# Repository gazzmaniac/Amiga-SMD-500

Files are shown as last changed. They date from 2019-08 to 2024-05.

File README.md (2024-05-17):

SMD 500+
Licensed under the CERN Open Hardware Licence Version 2 - Strongly Reciprocal.  https://cern-ohl.web.cern.ch/.

Warning and Disclaimer - May 2024
-------------------------------------------------------
Be advised that this project was only developed to a working prototype.  It has not been updated since 2019.
There are significant issues with it, not least of which are many of the holes and plugs do not line up with the A500 case.
If you want to build a replacement A500 or A500+ you should build a different project.
These files are made available in case somebody ever wants to use them as the basis for another project.
No support will be given by the author should you choose to ignore this advice and build it anyway.
Note the change in license.  Feel free to use this project but I do ask that any derivative projects give credit and are also open source.
No other changes have been made to this project.

Introduction
-------------------------------------------------------
The SMD 500+ project is a re-creation of the great Commodore Amiga 500/500+ using modern surface mounted components except for the CPU, custom chips, and CIAs.

The schematics are based on the schematics provided by Commodore in the Amiga 500+ user manual.
Each of the SMD components (except for the chip ram) was verified as available from Mouser in June 2019.  Anyone looking to construct the board would need a donor A500/A500+ or A2000 board in order to obtain the custom chips.

Features
-------------------------------------------------------
Certain experimental features have been added, most notably the ability to use either the 1 mb 8372 Agnus or the 2 mb 8375 Agnus, which are not pin-compatible with each other.  The board is set up to use the 8375 by default but can be changed simply by changing a couple of jumpers.

SVideo and Composite is supplied by an AD723 PAL encoder.  PAL only at this stage (sorry America).

The rechargeable battery has been substituted for a coin cell and diode (Aminet hack) and the RTC area has been slightly modified to allow for the RTC72421 IC to be used.

An option for a single HYB5118160BSJ 1Mx16 2 mb chip ram IC is available instead of using the eight 256kx4 TTH ICs.  The board is set up for the HYB5118160BSJ by default but can easily be changed with jumpers.  Note this modification is probably the most experimental of the lot and I am not 100% confident that there is not a mistake.

The power input socket is the same as Chucky Hertell's Re-Amiga 1200 board - i.e. you can use either the normal square DIN or a round DIN.

The EMF filters have been replaced with resistors and capacitors same as on the Amiga 1200.

Version 0.11 and 0.12 notes
-------------------------------------------------------
Minor revisions to fix a problem with the solder mask layer

Version 0.1 notes (also in the schematic)
-------------------------------------------------------

ADDED OPTION FOR ONE HYB5118160BSJ 1Mx16BIT CHIP RAM IC
REMOVED A501+ (PP12&13) FROM THESE SCHEMATICS 
(CONNECTOR P9 IS STILL THERE)

CHANGED BT9 TO COIN CELL AND DIODE
MINOR MODIFICATION TO ALLOW RTC72421

ADDED OPTION FOR AGNUS 8572.  CHANGE JP2 FOR 8572 
AND INSTALL FB101.1

ADD OPTION FOR ROUND DIN POWER INPUT

RESISTOR PACKS CHANGED FOR INDIVIDUAL RESISTORS

RTC REMOVED FROM A501 SCHEMATIC

REPLACED EMF FILTERS ON JOY1, JOY2, PARALLEL, SERIAL,
EXTERNAL FLOPPY, VIDEO OUT, CLOCKS, AUDIO, KB
WITH Rs, Cs, & FBs, A LA A1200

SVIDEO AND COLOUR COMPOSITE OUTPUT USING  AD723

U33.1 AND C33.1 REQUIRED IF USING AD723 OR 8372.

ONLY POPULATE EITHER U201 (2 MB SMD HYB5118160BSJ 1Mx16)
OR U16-23 (256Kx4 TTH FROM A500+).  

POPULATE C297-C299 FOR U201
POPULATE C16-C23 AND R209 FOR U16-U23

DO NOT INSTALL TRAP DOOR RAM WHEN U24 IS POPULATED

IF USING 1 MB AGNUS DO NOT INSTALL TRAP DOOR 
WHEN U20-23 ARE POPULATED

JUMPERS SET TO USE U201 AS DEFAULT
JP4 SET TO BYPASS U32 AS U201 HAS AN A9 LINE
JP98 CONNECTS THE TWO _RAS LINES

IF USING TTH 256Kx4 ICS (SAME AS ORIGINAL A500+ MACHINE)
POPULATE U32 AND BREAK JP4 AND JP98
JP3 SWAPS UPPER AND LOWER RAM BANKS FOR 256Kx4 CHIPS

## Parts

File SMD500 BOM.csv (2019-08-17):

Id | Designator | Package | Quantity | Designation | Supplier and ref
1 | U5 | DIP-48_W15.24mm_LongPads | 1 | 5719_Gary
2 | U7,U8 | DIP-40_W15.24mm_LongPads | 2 | 8520_CIA
3 | U39 | SOIC127P600X175-14N | 1 | MAX1489ECSD+
4 | R456,R458,R454 | R_0805_2012Metric_Pad1.15x1.40mm_HandSolder | 3 | 374R
5 | HY1 | PinHeader_1x22_P2.54mm_Vertical | 1 | VIDEOHYBRID
6 | U41,U40 | SOIC127P1030X265-20N | 2 | SN74HCT245DWR
7 | U2.2 | PLCC-84_THT-Socket | 1 | 8372_FatAgnus1MB
8 | BT9 | SMTU2032LF | 1 | COINCELL
9 | U2.1 | PLCC-84_THT-Socket | 1 | 8375_FatAgnus2MB
10 | U201 | SOJ-42 | 1 | HYB5118160BSJ
11 | U20,U23,U22,U21,U19,U18,U17,U16 | DIP-20_W7.62mm_LongPads | 8 | HYB514256B
12 | U11,U34,U13 | SOIC127P1030X265-20N | 3 | SN74LS373DW
13 | U10,U12 | SOIC127P1030X265-20N | 2 | SN74LS244DW
14 | U1 | DIP-64_W22.86mm_LongPads | 1 | 68000D
15 | G***,G***,G*** | RedKeg500 | 3 | LOGO
16 | TC9 | C_Trimmer_Voltronics_JZ | 1 | 8-40 pF (JZ400)
17 | C402,C401,C307 | CAPAE1350X1400N | 3 | 1000 uF
18 | D912,D99 | SOD3716X115N | 2 | 1N4148W-7-F
19 | Y460 | XTAL_HC49 | 1 | 17.734 475 MHz 18 pF
20 | Y9 | LFXTAL002995BULK | 1 | LFXTAL002995Bulk
21 | X1 | Oscillator_DIP-14 | 1 | ACO-28.37516MHz
22 | V20,V19,V18,V17,V16,V15,V14,V13,V12,V11,V10,V9,V8,V7,V6,V5,V4,V3,V2,V1 | SolderWirePad_1x01_Drill0.8mm | 20 | Conn_01x01_Male
23 | U45 | AD723ARUZ | 1 | AD723ARUZ
24 | U42 | SOIC127P600X175-8N | 1 | NE555DR
25 | U38 | SOIC127P600X175-14N | 1 | MAX1488ECSD+
26 | U37 | SN74LS32NSR | 1 | 74LS32
27 | U36 | SOIC127P600X175-14N | 1 | SN74LS05DR
28 | U35 | SOIC127P1032X265-20N | 1 | N74F244D
29 | U33.1 | SN74F04DR | 1 | SN74F04DR
30 | U33 | SOIC127P600X175-16N | 1 | SN74F258D
31 | U32 | MC74AC139DR2G | 1 | MC74AC139DR2G
32 | U15 | SN74LS157DR | 1 | SN74LS157DR
33 | U14 | SOIC127P600X175-14N | 1 | TL084
34 | U9 | DIP-18_W7.62mm_LongPads | 1 | RTC72421
35 | U6 | DIP-42_W15.24mm_Socket_LongPads | 1 | ROM_SOCKET
36 | U4 | DIP-48_W15.24mm_LongPads | 1 | 8373_DeniseECS
37 | U3 | DIP-48_W15.24mm_LongPads | 1 | 8364_Paula
38 | TP9 | TestPoint_Pad_1.0x1.0mm | 1 | TestPoint
39 | RP501.5,RP501.6,RP501.4,RP501.3,RP501.2,RP501.7,RP501.8,RP501.1,R914,R912,R506,R505,R501,R339,R333,R332,R323,R322,R308,R306 | R_0805_2012Metric_Pad1.15x1.40mm_HandSolder | 20 | 10K
40 | RP403.2,RP403.5,RP402.1,RP402.2,RP402.3,RP402.4,RP402.5,RE531,RE434 | R_0805_2012Metric_Pad1.15x1.40mm_HandSolder | 9 | 47R
41 | RP403.3,RP403.4,RP403.1,RP203.2,RP203.1,RP203.3,RP203.4,RP203.5,RP202.2,RP202.4,RP202.1,RP202.3,RP202.5,RP201.1,RP201.3,RP201.2,RP201.5,RP201.4,RE626,RE619,RE618,RE616,RE612,RE611,RE538,RE537,RE536,RE535,RE534,RE533,RE532,RE524,RE523,RE522,RE521,RE520,RE519,RE518,RE517,RE516,RE515,RE514,RE513,RE512,RE511,RE499,RE427,RE426,RE425,RE424,RE423,RE422,RE421,RE417,RE416,RE415,RE414,RE413,RE412,RE411,R109 | R_0805_2012Metric_Pad1.15x1.40mm_HandSolder | 61 | 68R
42 | RP401.4,RP401.6,RP401.3,RP401.2,RP401.1,RP401.7,RP401.8,RP401.5,RP111.6,RP111.5,RP111.4,RP111.9,RP111.8,RP111.3,RP111.2,RP111.7,RP111.1,RP110.8,RP110.2,RP110.3,RP110.4,RP110.5,RP110.6,RP110.7,RP110.9,RP110.1,RP109.1,RP109.7,RP109.6,RP109.5,RP109.4,RP109.3,RP109.2,RP109.8,RP109.9,RP108.2,RP108.8,RP108.3,RP108.4,RP108.5,RP108.6,RP108.7,RP108.1,RP108.9,RP107.9,RP107.1,RP107.7,RP107.8,RP107.2,RP107.4,RP107.5,RP107.3,RP107.6,RP106.7,RP106.6,RP106.5,RP106.1,RP106.4,RP106.8,RP106.3,RP106.2,RP106.9,RP105.9,RP105.7,RP105.2,RP105.3,RP105.4,RP105.6,RP105.5,RP105.1,RP102.4,RP102.7,RP102.3,RP102.6,RP102.1,RP102.5,RP102.2,RP101.8,RP101.2,RP101.1,RP101.3,RP101.4,RP101.5,RP101.6,RP101.7,R504,R503,R404,R403,R402,R209,R202,R201 | R_0805_2012Metric_Pad1.15x1.40mm_HandSolder | 93 | 4.7K
43 | RP104.2,RP104.1,RP104.4,RP104.5,RP104.7,RP104.8,RP104.9,RP104.3,RP104.6 | R_0805_2012Metric_Pad1.15x1.40mm_HandSolder | 9 | 470R
44 | RP103.3,RP103.2,RP103.4,RP103.1 | R_0805_2012Metric_Pad1.15x1.40mm_HandSolder | 4 | 39R
45 | RE625,RE624,RE623,RE622,RE621,RE620,RE617,RE615,RE614,RE613,RE105,RE104 | R_0805_2012Metric_Pad1.15x1.40mm_HandSolder | 12 | 27R
46 | RE444,RE443,RE442,RE441,RE303,RE302 | R_0805_2012Metric_Pad1.15x1.40mm_HandSolder | 6 | 0R
47 | R916,R915,R713,R334,R324,R305,R304,R303,R192,R191 | R_0805_2012Metric_Pad1.15x1.40mm_HandSolder | 10 | 1K
48 | R712 | R_0805_2012Metric_Pad1.15x1.40mm_HandSolder | 1 | 47K
49 | R711,R461 | R_0805_2012Metric_Pad1.15x1.40mm_HandSolder | 2 | 1M
50 | R507 | R_0805_2012Metric_Pad1.15x1.40mm_HandSolder | 1 | 100R
51 | R502,R307 | R_0805_2012Metric_Pad1.15x1.40mm_HandSolder | 2 | 2.7K
52 | R460 | R_0805_2012Metric_Pad1.15x1.40mm_HandSolder | 1 | 200R
53 | R457,R455,R453 | R_0805_2012Metric_Pad1.15x1.40mm_HandSolder | 3 | 300R
54 | R452,R451,R450 | R_0805_2012Metric_Pad1.15x1.40mm_HandSolder | 3 | 75R
55 | R409 | R_0805_2012Metric_Pad1.15x1.40mm_HandSolder | 1 | 150R
56 | R408,R406,R401 | R_0805_2012Metric_Pad1.15x1.40mm_HandSolder | 3 | 4.7R 0.5W
57 | R405 | R_0805_2012Metric_Pad1.15x1.40mm_HandSolder | 1 | 0.47R 0.5W
58 | R336,R326 | R_0805_2012Metric_Pad1.15x1.40mm_HandSolder | 2 | 470K
59 | R335,R325 | R_0805_2012Metric_Pad1.15x1.40mm_HandSolder | 2 | 390R
60 | R331,R321 | R_0805_2012Metric_Pad1.15x1.40mm_HandSolder | 2 | 360R
61 | R309 | R_0805_2012Metric_Pad1.15x1.40mm_HandSolder | 1 | 1R 0.5W
62 | R302,R301 | R_0805_2012Metric_Pad1.15x1.40mm_HandSolder | 2 | 10R
63 | R114,R112,R111 | R_0805_2012Metric_Pad1.15x1.40mm_HandSolder | 3 | 68
64 | R113,R107,R106,R105,R104,R103 | R_0805_2012Metric_Pad1.15x1.40mm_HandSolder | 6 | 47
65 | R102,R101 | R_0805_2012Metric_Pad1.15x1.40mm_HandSolder | 2 | 27
66 | Q711,Q501 | SOT-23-3 | 2 | MMBT3904-TP
67 | Q503,Q502,Q301 | SOT-23-3 | 3 | MMBT3906-TP
68 | Q331,Q321 | PMBF4391 | 2 | PMBF4391
69 | P9 | PinHeader_2x28_P2.54mm_Vertical(Mirror) | 1 | Conn_02x28_Odd_Even
70 | P1 | 86 pin edge connector | 1 | EDGE86
71 | MT7,MT6,MT5,MT4,MT2,MT1 | MountingHole_4mm_Pad_Via | 6 | MountingHole_Pad
72 | LF1 | Amiga Line Filter | 1 | AmigaLineFilter
73 | L450 | L_0805_2012Metric_Pad1.15x1.40mm_HandSolder | 1 | 68uH
74 | JP450,JP199,JP98,JP10.2,JP10.1,JP1 | SolderJumper-2_P1.3mm_Bridged_Pad1.0x1.5mm | 6 | SolderJumper_2_Bridged
75 | JP99.1,JP99.2,JP8,JP7.2,JP7.1,JP4.2,JP4.1 | SolderJumper-3_P1.3mm_Bridged12_Pad1.0x1.5mm_NumberLabels | 7 | SolderJumper_3_Bridged12
76 | JP11 | SolderJumper-3_P1.3mm_Bridged12_Pad1.0x1.5mm_NumberLabels | 1 | SolderJumper_3_Bridged1-2
77 | JP9 | SolderJumper-2_P1.3mm_Open_Pad1.0x1.5mm | 1 | SolderJumper_2_Open
78 | JP3.1,JP3.2 | SolderJumper-2_P1.3mm_Bridged_Pad1.0x1.5mm | 2 | Jumper_2_Bridged
79 | JP2 | SolderJumper-3_P1.3mm_Bridged12_Pad1.0x1.5mm_NumberLabels | 1 | SolderJumper_3_Bridged12_2
80 | FB802,E435 | R_0805_2012Metric_Pad1.15x1.40mm_HandSolder | 2 | FB
81 | FB704,FB703,FB702,FB602,FB601,E498,E433,E432,E431,E407,E406.1,E406.2,E405,E404,E403,E402,E110,E101 | R_0805_2012Metric_Pad1.15x1.40mm_HandSolder | 18 | FB200R
82 | FB102 | R_0805_2012Metric_Pad1.15x1.40mm_HandSolder | 1 | 150R@100MHz
83 | FB101 | R_0805_2012Metric_Pad1.15x1.40mm_HandSolder | 1 | 68R@100MHz
84 | E794,E793,E792,E791 | C_0805_2012Metric | 4 | 47 pF
85 | E666 | C_0805_2012Metric | 1 | 22 pF
86 | E632,E631 | C_0805_2012Metric | 2 | 100 pF
87 | E503,E502,E501 | R_0805_2012Metric_Pad1.15x1.40mm_HandSolder | 3 | 47R 0.5W
88 | E306,E305 | C_0805_2012Metric_Pad1.15x1.40mm_HandSolder | 2 | 270 pF
89 | E109,E108,E107,E106,E103,E102,C403 | C_0805_2012Metric_Pad1.15x1.40mm_HandSolder | 7 | 47 pF
90 | D501 | D_DO-35_SOD27_P7.62mm_Horizontal | 1 | 1N914
91 | CN45,CN15 | HDRV4W69P0X250_1X4_1000X500X1040P | 2 | Conn_01x04
92 | CN14,CN12 | TE_2-171825-4 | 2 | 2-171825-4
93 | CN13 | PinHeader_1x08_P2.54mm_Vertical | 1 | 1x8HEADER
94 | CN11 | PinHeader_2x17_P2.54mm_Vertical | 1 | 2x17
95 | CN10 | PJRAN1X1U03AUX | 1 | PJRAN1X1U03AUX(YELLOW)
96 | CN9 | DSUB-23_Male_Horizontal_P2.77x2.84mm_EdgePinOffset4.94mm_Housed_MountingHolesOffset7.48mm | 1 | DB23
97 | CN8 | A500 Power | 1 | SQ&RNDDIN
98 | CN7 | D25S33E4PA00LF | 1 | DB25S
99 | CN6 | D25P13B4PA00LF | 1 | DB25P
100 | CN5 | DSUB-23_Female_Horizontal_P2.77x2.84mm_EdgePinOffset4.94mm_Housed_MountingHolesOffset7.48mm | 1 | DB23_Female_MountingHoles
101 | CN4 | PJRAN1X1U03AUX | 1 | PJRAN1X1U02AUX(WHITE)
102 | CN3 | PJRAN1X1U03AUX | 1 | PJRAN1X1U03AUX(RED)
103 | CN2,CN1 | D09P13B4PA00LF | 2 | DB9-M
104 | CE704,CE703,CE702,CE602,CE601,CE531,CE501,CE498,CE407,CE405,CE404,CE403,CE402,CE110,CE101,C803,C802,C801,C800,C713,C701,C308,C39,C37,C36,C35,C34,C33,C33.1,C32,C15,C12,C10,C8,C7 | C_0805_2012Metric_Pad1.15x1.40mm_HandSolder | 35 | 0.01 uF
105 | CE626,CE625,CE624,CE623,CE622,CE621,CE620,CE619,CE618,CE617,CE616,CE615,CE614,CE613,CE612,CE611,CE538,CE537,CE536,CE535,CE534,CE533,CE532,CE525,CE524,CE523,CE522,CE521,CE519,CE518,CE517,CE516,CE515,CE514,CE513,CE512,CE511,CE499,CE434,CE433,CE432,CE431,CE403.4,CE403.3,CE403.1,CE402.4,CE402.3,CE402.2,CE402.5 | C_0805_2012Metric_Pad1.15x1.40mm_HandSolder | 49 | 100 pF
106 | CE444,CE443,CE442,CE441,C423,C422,C421,C413,C412,C411 | C_0805_2012Metric_Pad1.15x1.40mm_HandSolder | 10 | 470 pF
107 | CE424,CE423,CE422,CE421,CE414,CE413,CE412,CE411,CE303,CE302,C332,C322 | C_0805_2012Metric_Pad1.15x1.40mm_HandSolder | 12 | 6800 pF
108 | CE408,CE401 | C_0805_2012Metric_Pad1.15x1.40mm_HandSolder | 2 | 0.22 uF
109 | CE105,CE104 | C_0805_2012Metric_Pad1.15x1.40mm_HandSolder | 2 | 68 pF
110 | C913 | EEEHB1E4R7AR | 1 | 4.7 uF
111 | C911 | C_0805_2012Metric_Pad1.15x1.40mm_HandSolder | 1 | 22 pF
112 | C822,C821 | CP_Elec_6.3x7.7 | 2 | 47 uF
113 | C816,C815,C814,C813,C812,C811 | CP_Elec_6.3x7.7 | 6 | 100 uF
114 | C804,C502,C501,C335,C325,C305,C302,C301,C42,C41,C40,C23,C22,C21,C20,C19,C18,C17,C16,C14,C13,C11,C9,C6,C5,C4,C3,C2,C1 | C_0805_2012Metric_Pad1.15x1.40mm_HandSolder | 29 | 0.33 uF
115 | C712,C306,C45.1 | CP_Elec_4x5.7 | 3 | 10 uF
116 | C711,C451,C450,C331,C321,C45.3,C45.2 | C_0805_2012Metric_Pad1.15x1.40mm_HandSolder | 7 | 0.1 uF
117 | C461 | C_0805_2012Metric_Pad1.15x1.40mm_HandSolder | 1 | 39 pF
118 | C460 | C_0805_2012Metric_Pad1.15x1.40mm_HandSolder | 1 | 33 pF
119 | C453 | C_0805_2012Metric_Pad1.15x1.40mm_HandSolder | 1 | 18 pF
120 | C452 | C_0805_2012Metric_Pad1.15x1.40mm_HandSolder | 1 | 0.1u
121 | C334,C324,C304,C303 | CP_Elec_6.3x5.3 | 4 | 22 uF
122 | C333,C323 | C_0805_2012Metric_Pad1.15x1.40mm_HandSolder | 2 | 3900 pF
123 | C314,C313,C312,C311 | C_0805_2012Metric_Pad1.15x1.40mm_HandSolder | 4 | 0.047 uF
124 | C299,C298 | C_0805_2012Metric_Pad1.15x1.40mm_HandSolder | 2 | 0.47 uF

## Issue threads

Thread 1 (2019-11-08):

Is there a forum or other discussion area?

abrugsch, 2019-11-08:
I found someone selling a copy of this this board on ebay and it's something that I wanted to do myself (glad to see you're using KiCad... I can contribute pull requests ;) ). The A500++ is all well and good but it uses the exact same through hole parts as the original. I'd like to see how people building this are getting on as I love that it has a load of the modern mods built right in.

Is there a dev thread on EAB? or a discord server such as Official Commodore Amiga, Retro Man Cave, Amiga Bill's?

gazzmaniac, 2019-11-09:
I haven't got any formal discussion etc. but I am making one and posting progress on Facebook at facebook.com/redkegtech.
I have no idea if anyone has got one running yet.  I've got an issue getting sync from Agnus but I'm away for work for a couple of weeks so progress has stalled.

Closed 2019-11-09.

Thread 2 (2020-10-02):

is this board tested?

arjanv, 2020-10-02:
is this board tested?

thanks

gazzmaniac, 2020-10-02:
It works but no guarantees.As per the readme.

  On Fri., 2 Oct. 2020 at 10:43 pm, arjanv<notifications@github.com> wrote:

is this board tested?

thanks

—
You are receiving this because you are subscribed to this thread.
Reply to this email directly, view it on GitHub, or unsubscribe.

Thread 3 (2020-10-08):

JP98 RAS joined won't work

LIV2, 2020-10-08:
Hi, first of all great work! Love the project

Just thought I'd let you know that recently I was making a Megachip clone for the A500 and found that joining the RAS lines just resulted in a green screen. I had to make use of an OR gate to get this working - an 74AHC1G08 in my case.

Presumably this is because the RAS lines are not open-collector and fight each other when you simply join them together

mariuszk911, 2020-10-08:
Or just use two diodes... Like on 2M Mod for 8A1 using SOJ memory modules.

gazzmaniac, 2022-04-20:
I never did get the single ram IC solution working.  I'm looking at doing a revision later in the year and will have chip ram on two chips.

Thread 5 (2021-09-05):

gerber errors

kipper2k, 2021-09-05:
Hi all, i am looking at the gerbers i uploaded to...  https://gerber-viewer.easyeda.com/showcase/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

I found some traces that seem to be incorrect, here is a picture, there may be more.

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

gazzmaniac, 2022-04-20:
Hi Kipper!
Thanks for letting me know.  I am looking at doing a revision this year, and intend to replace the TTH ram with two SMD chips like the A1200 has.

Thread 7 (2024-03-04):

A question about fitting the board

leventpekcan, 2024-03-04:
Hello,

I received a fully built, working SMD500+ from my friend and trying to build myself a modern A500+ with it. The problem is, the board does not fit into the original metal shielding of A500+. Even without the shielding, some of the screw holes does not align with the bottom plastic part (Original A500+). What could be the problem?

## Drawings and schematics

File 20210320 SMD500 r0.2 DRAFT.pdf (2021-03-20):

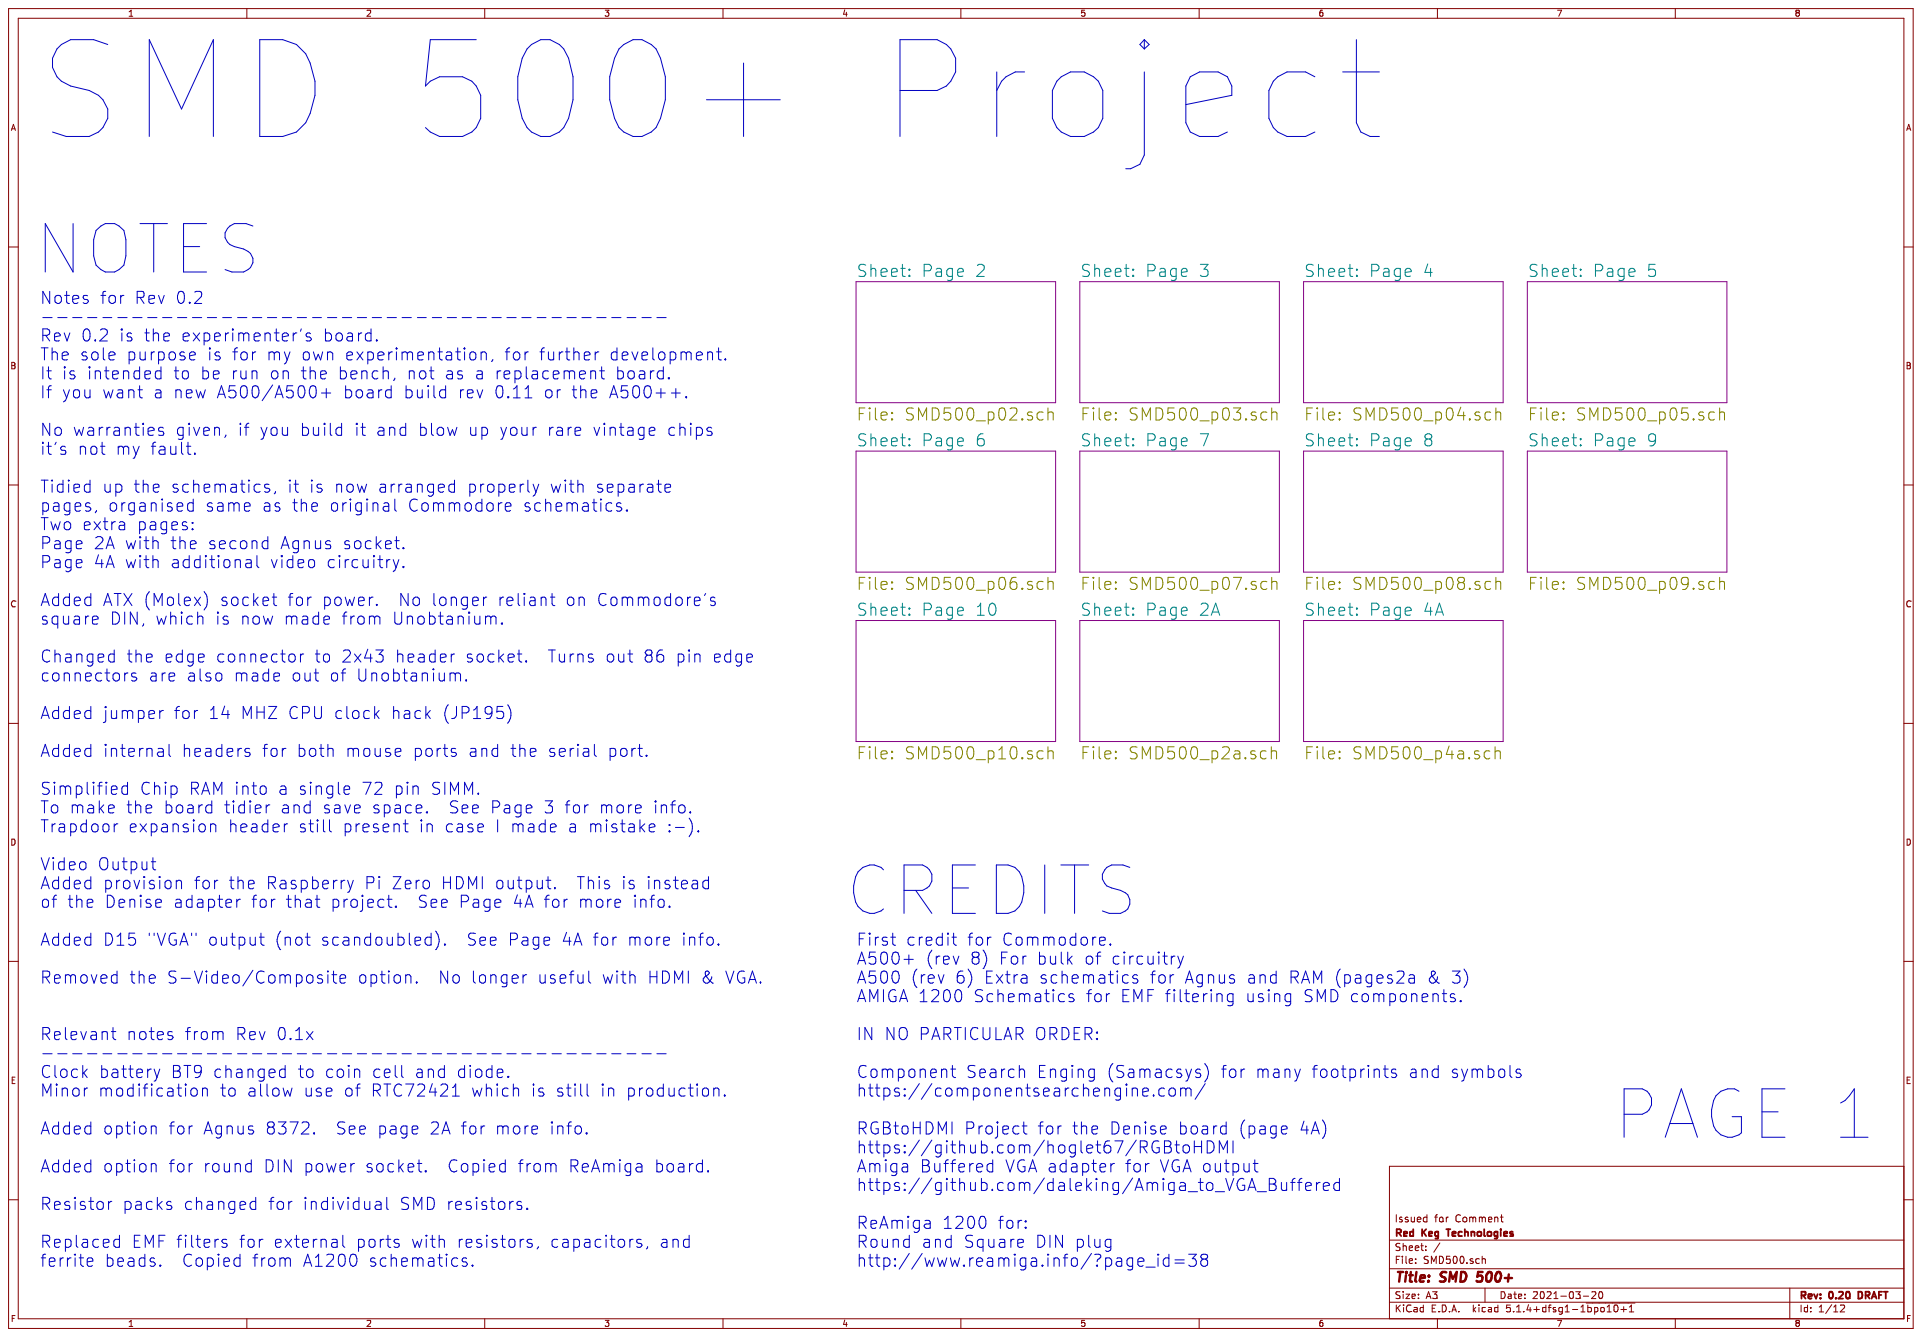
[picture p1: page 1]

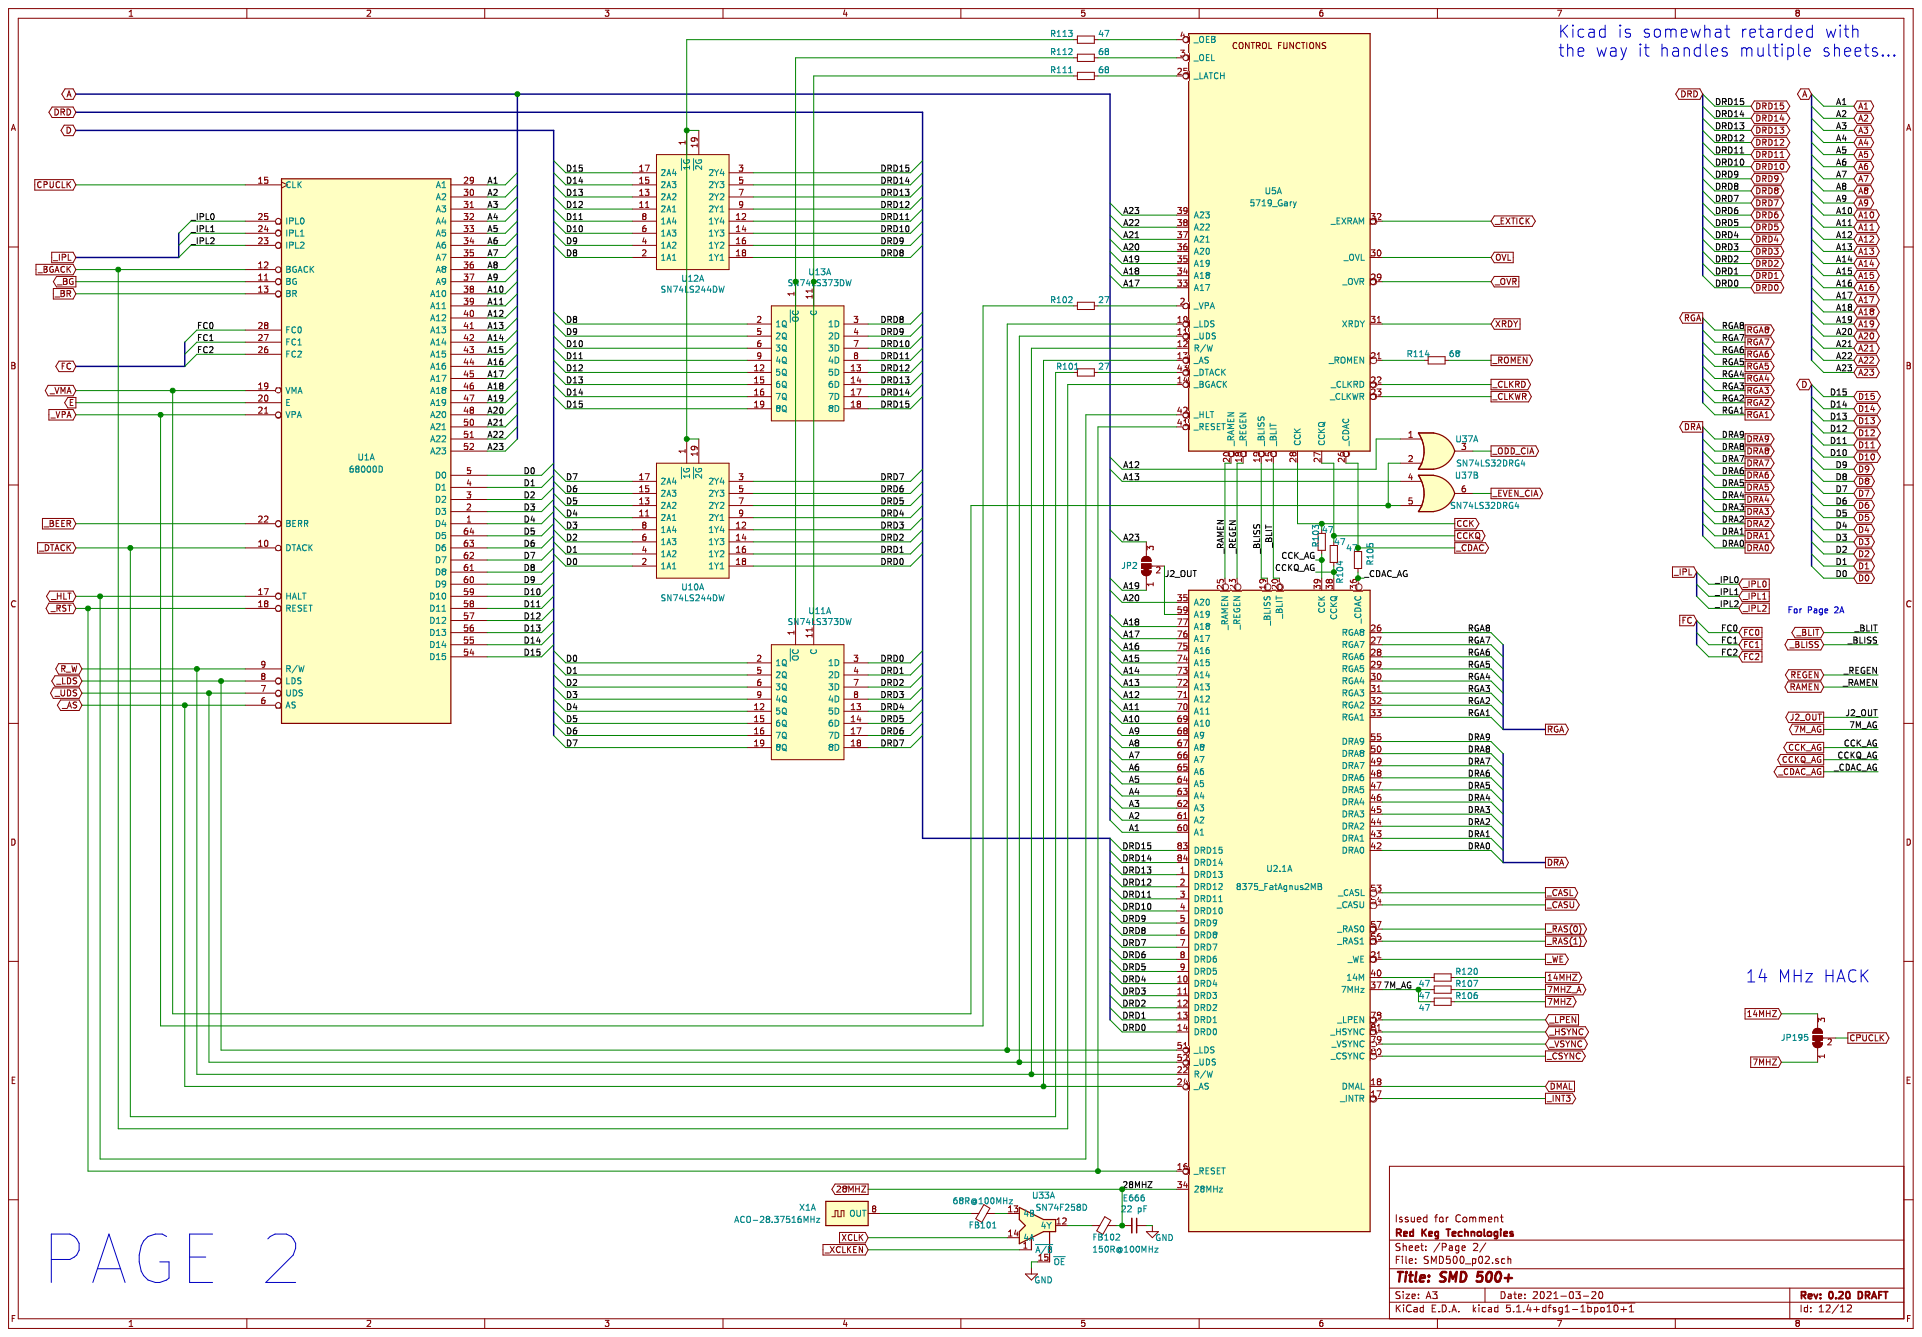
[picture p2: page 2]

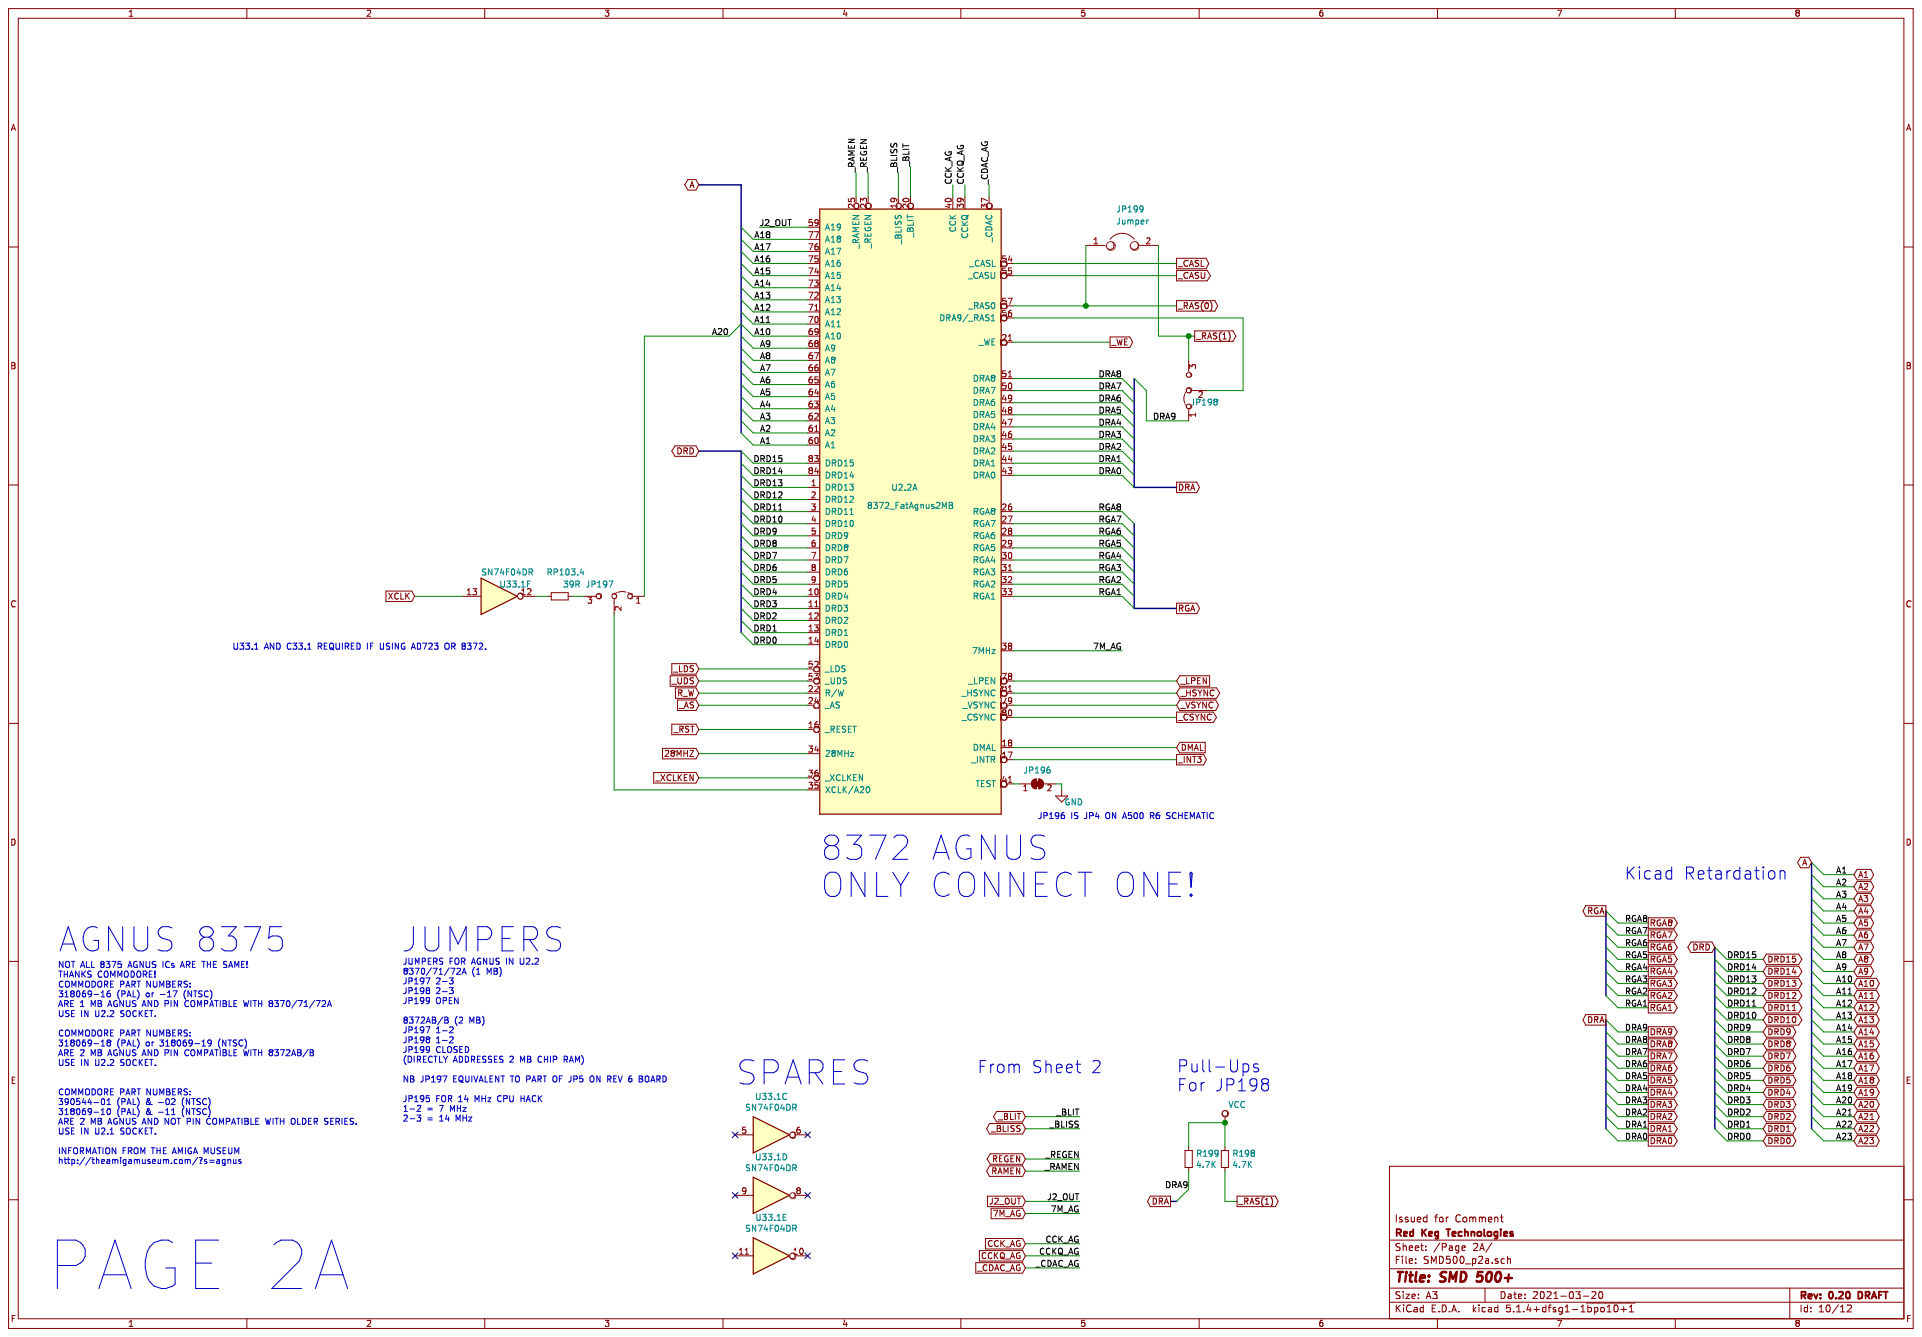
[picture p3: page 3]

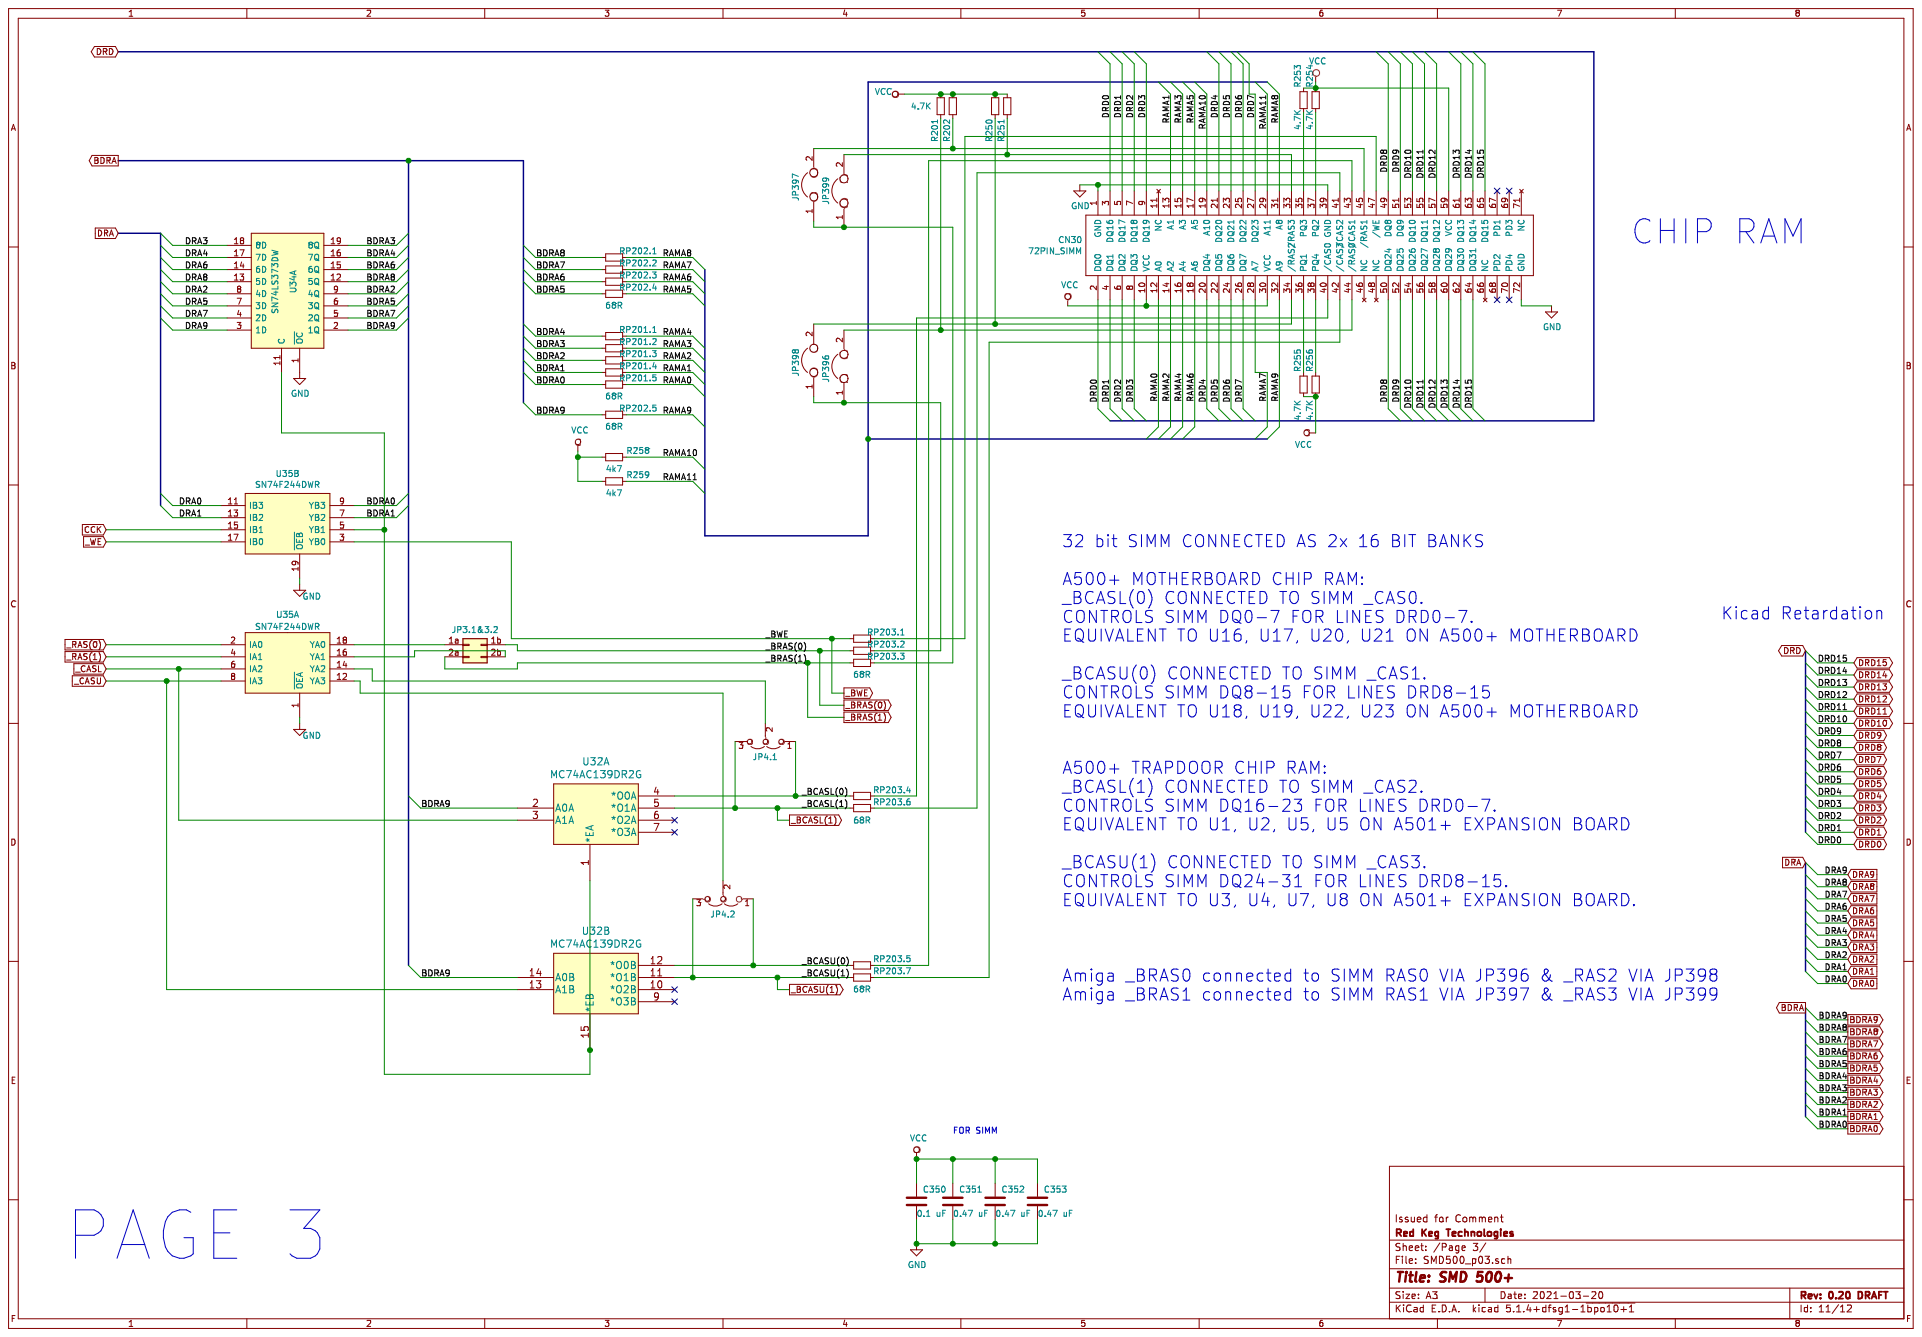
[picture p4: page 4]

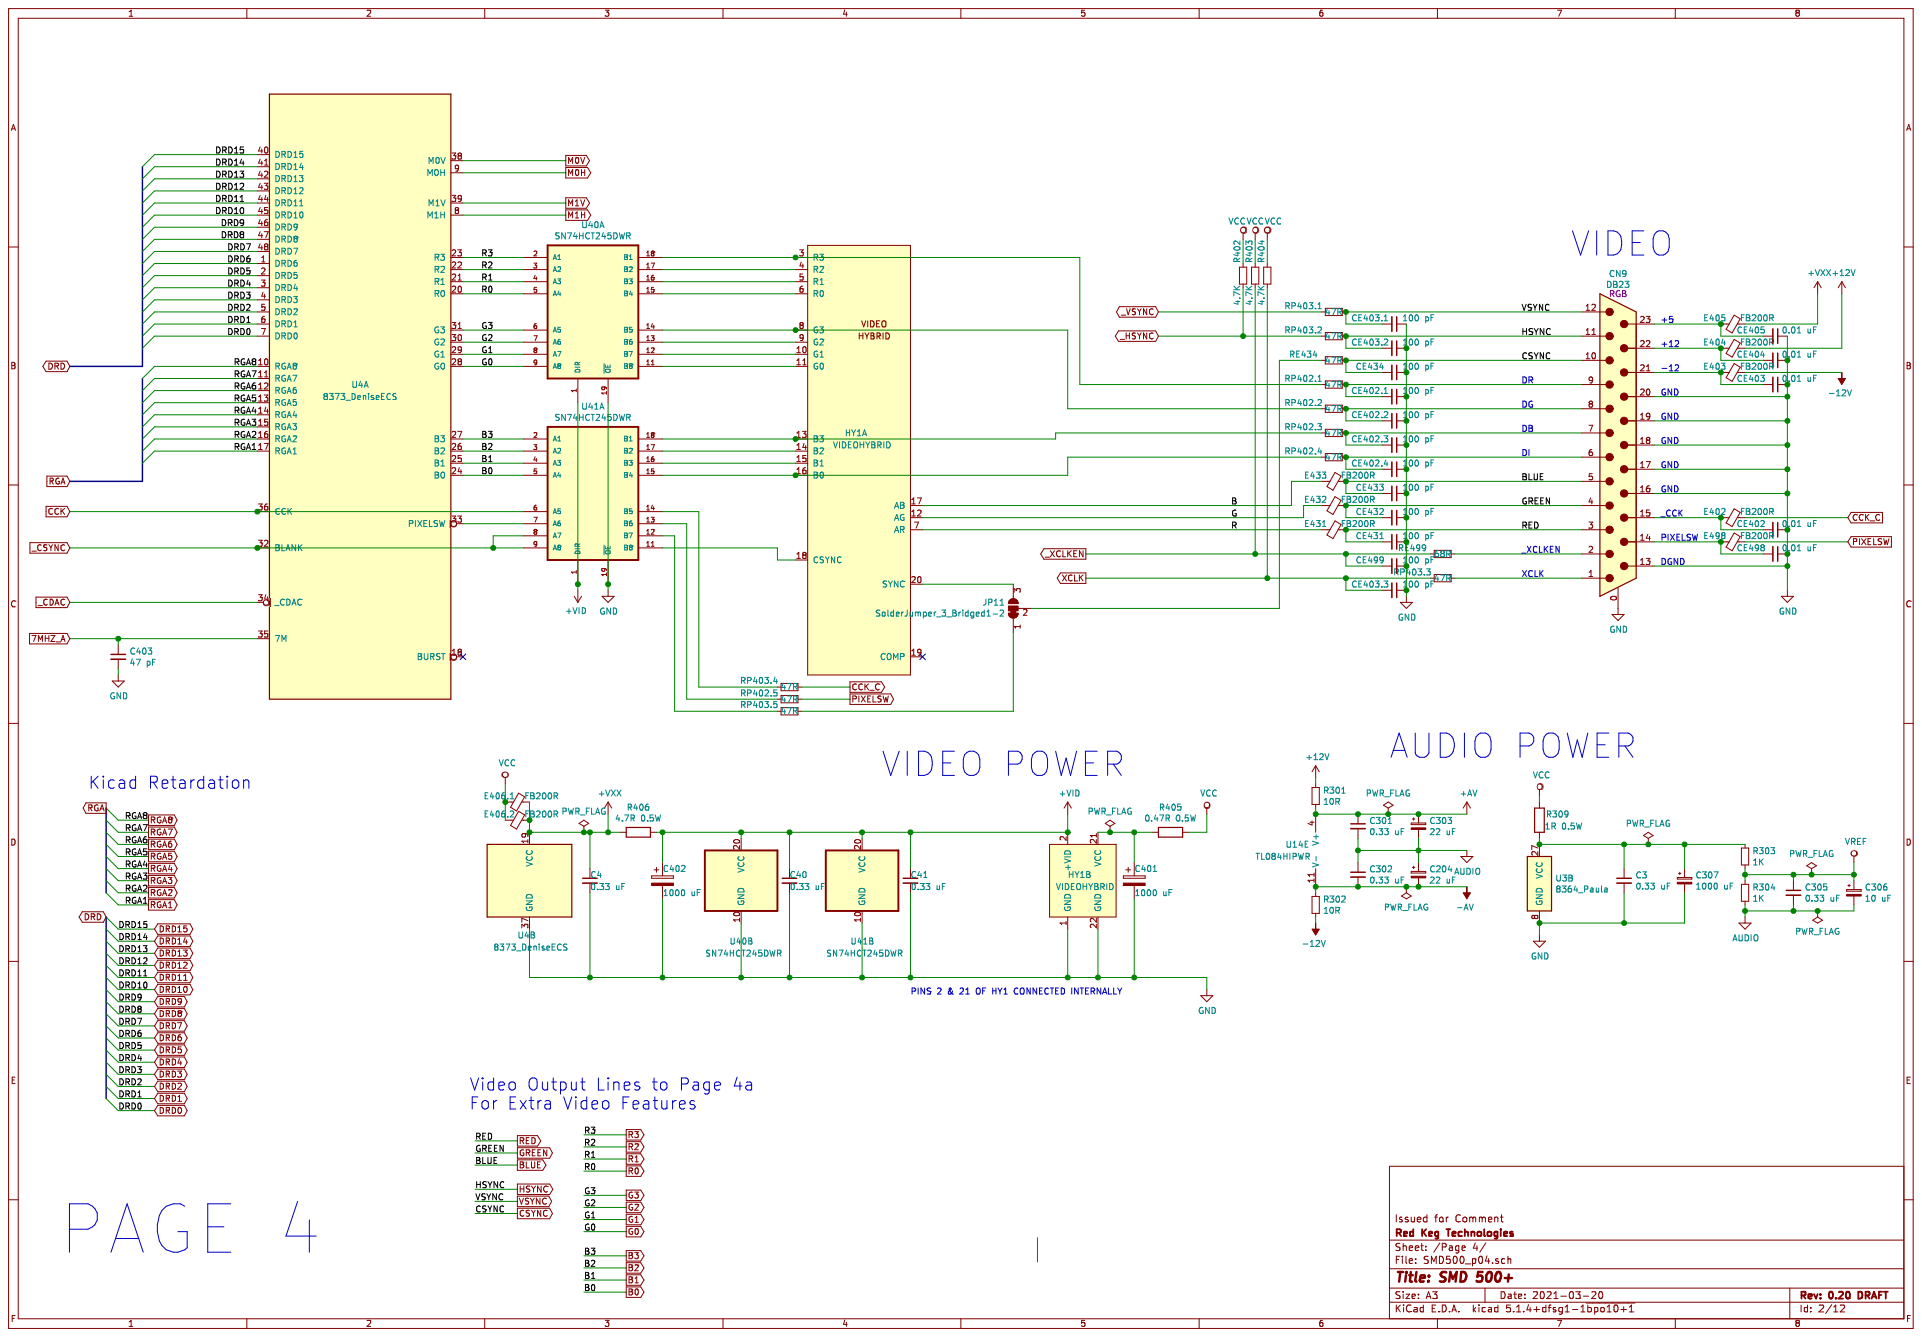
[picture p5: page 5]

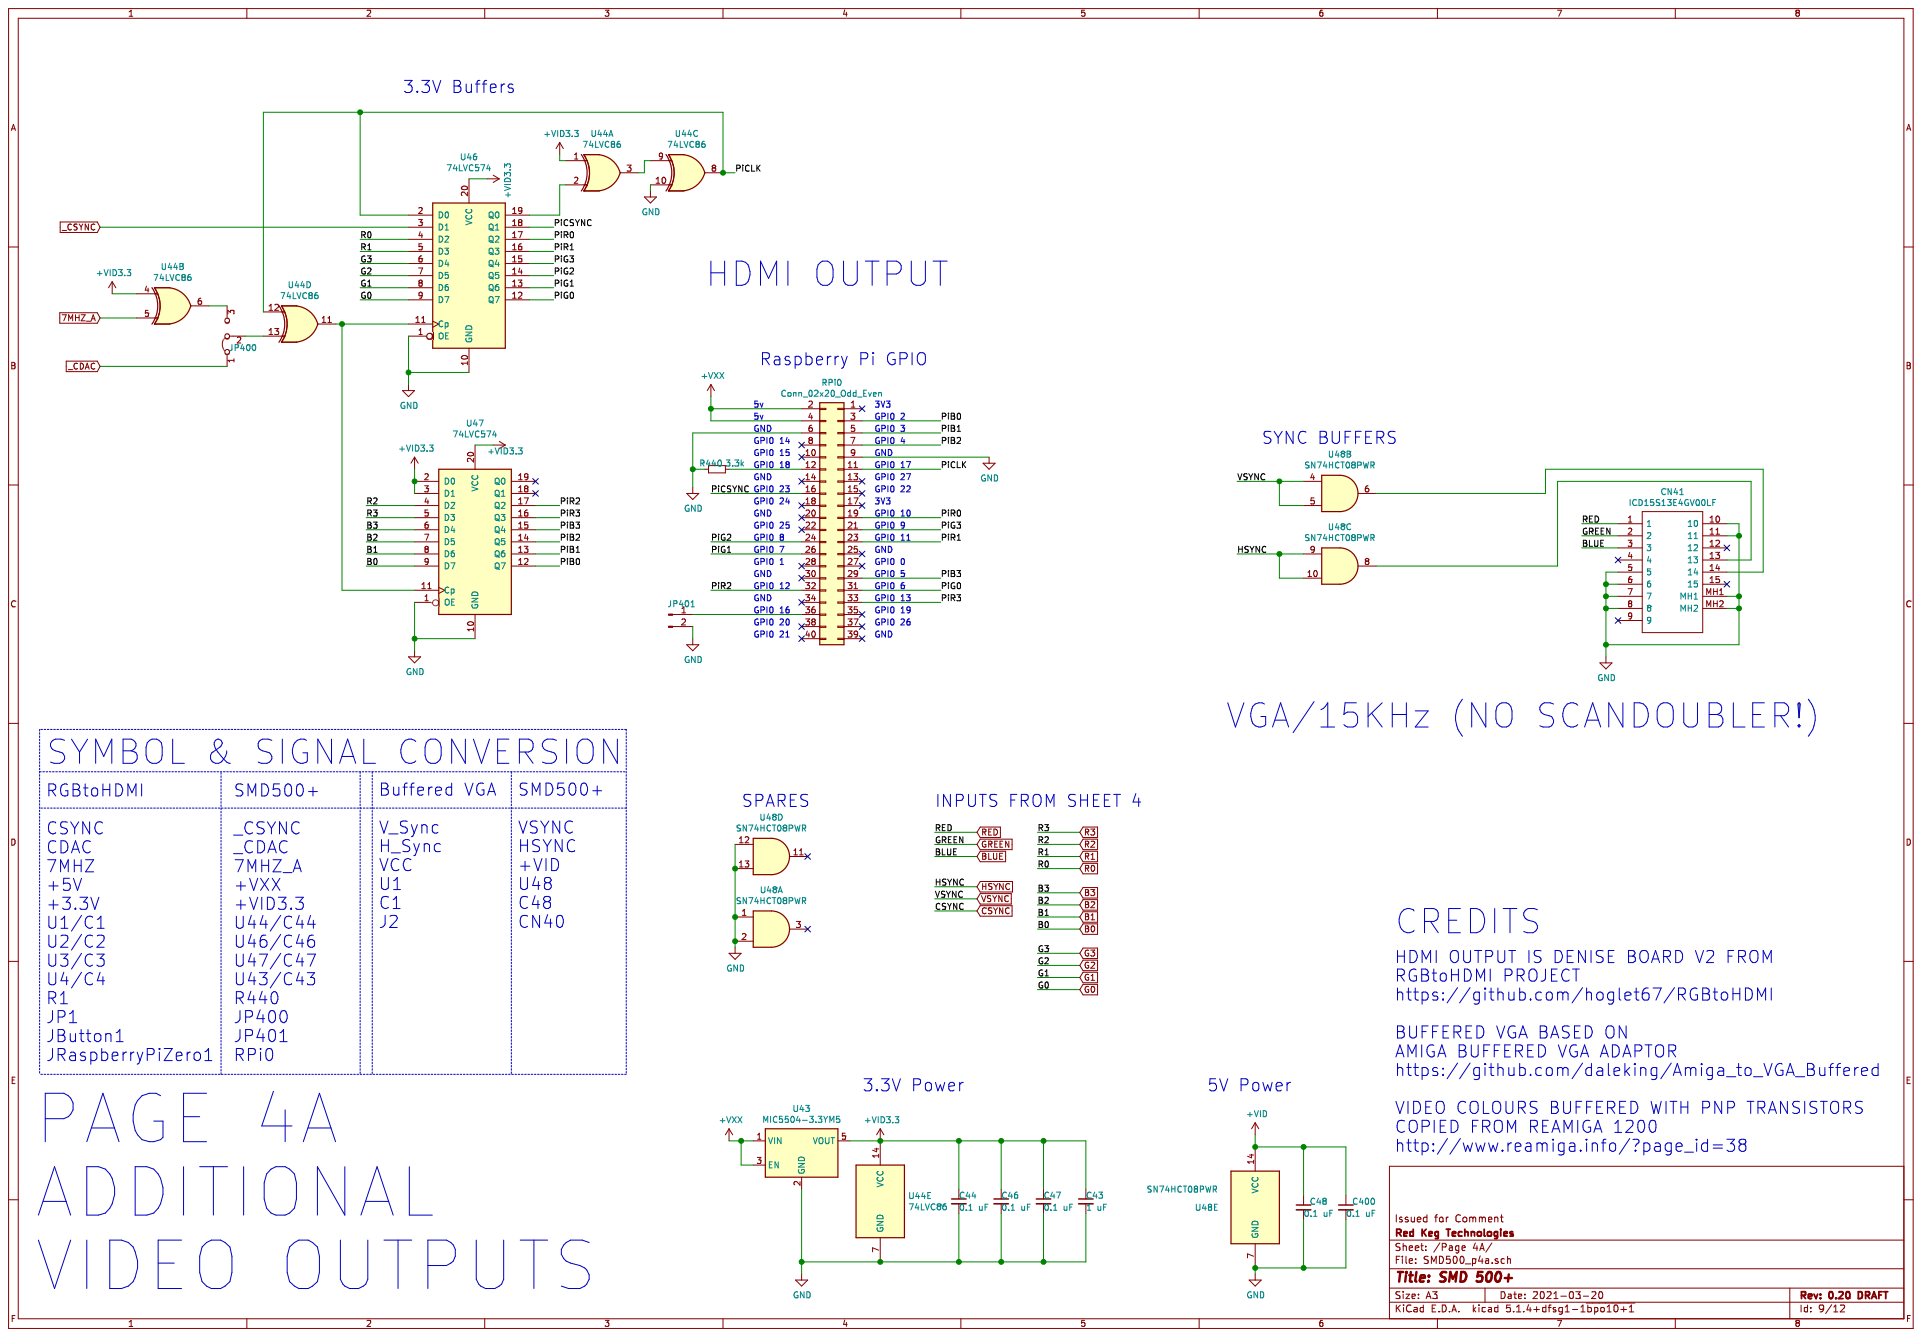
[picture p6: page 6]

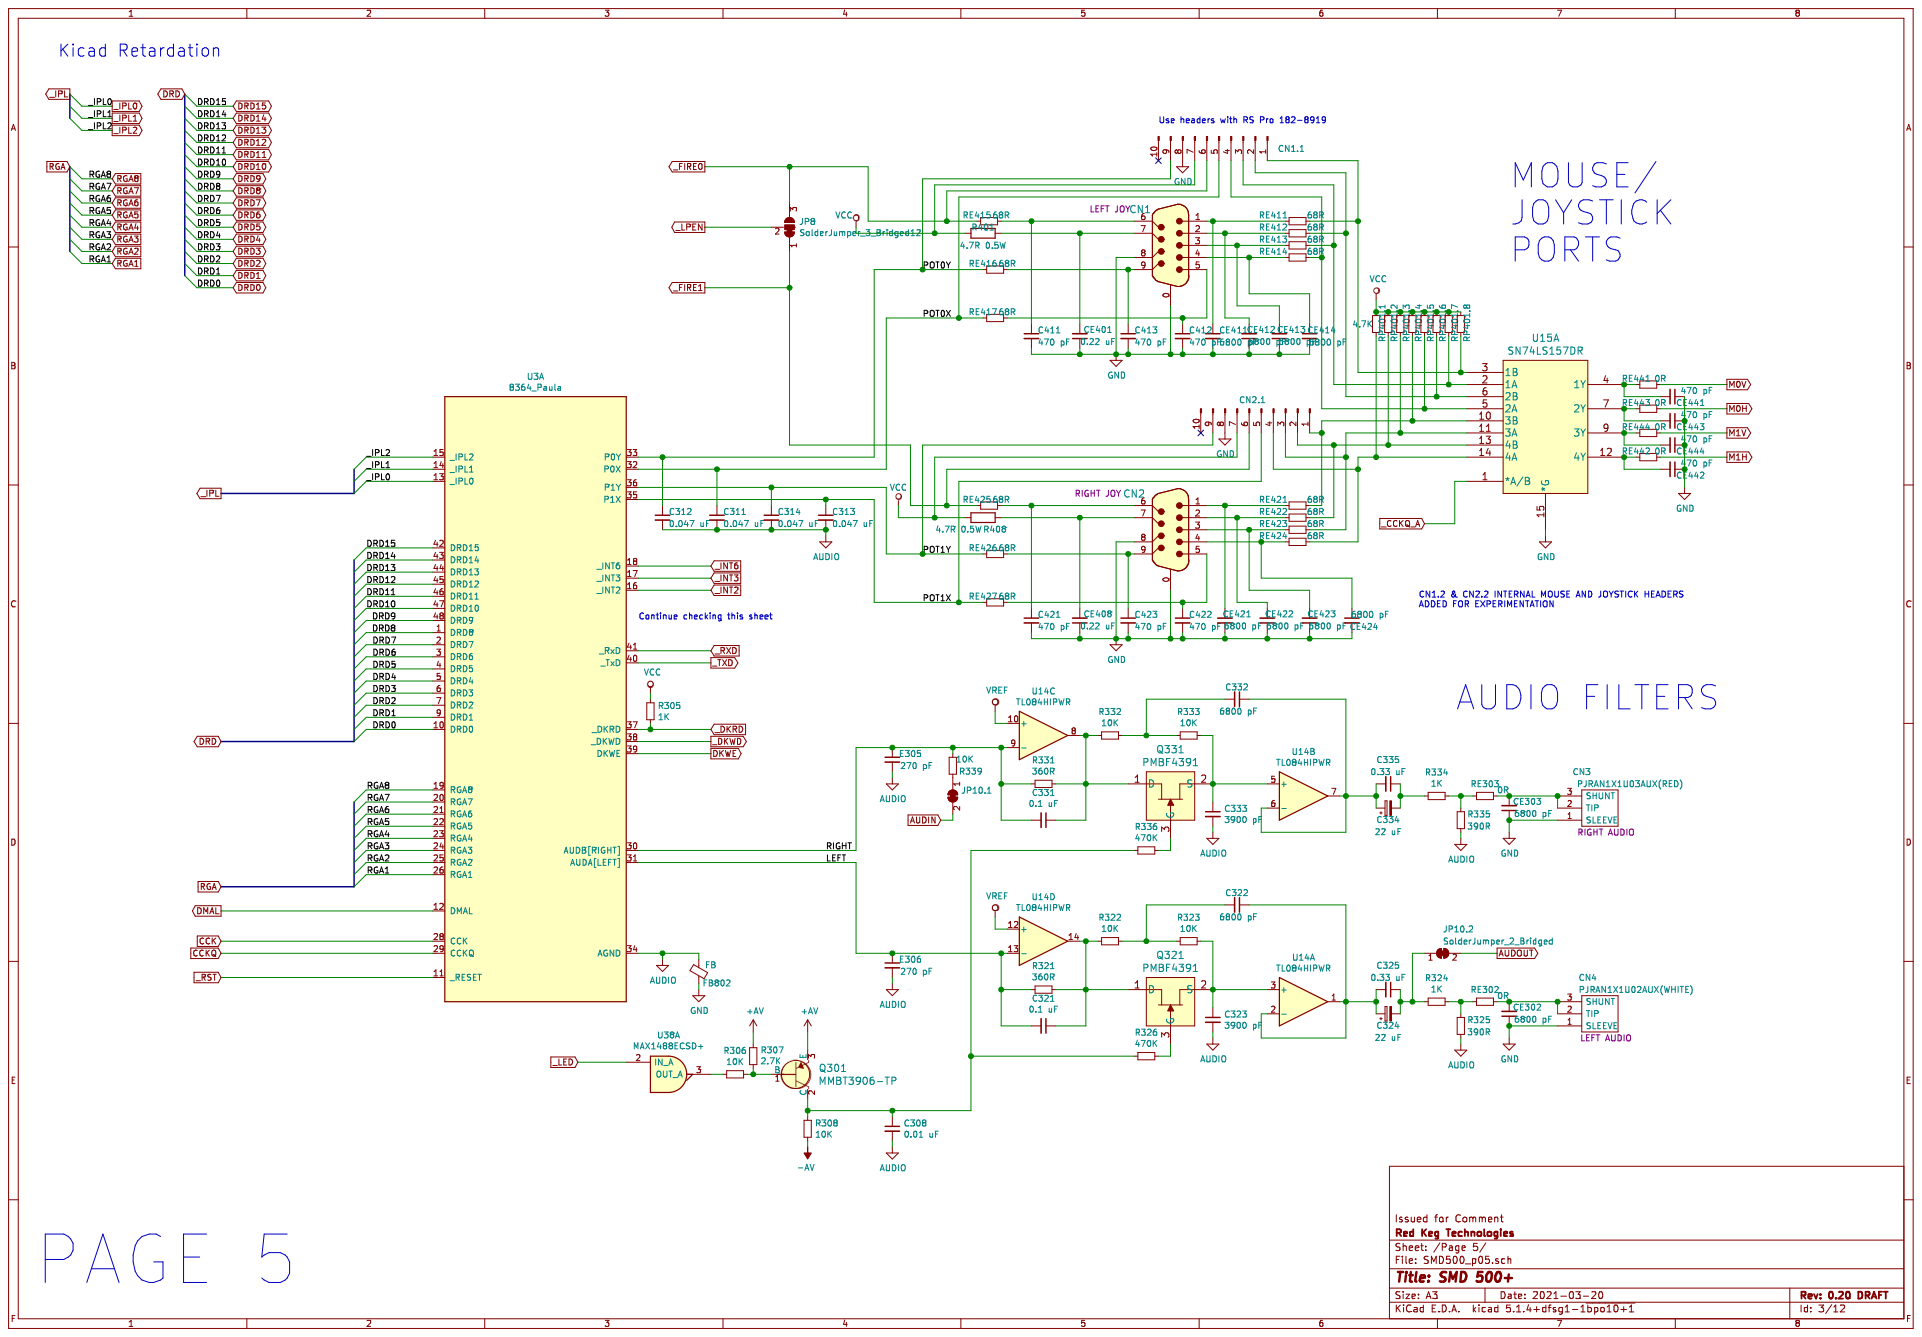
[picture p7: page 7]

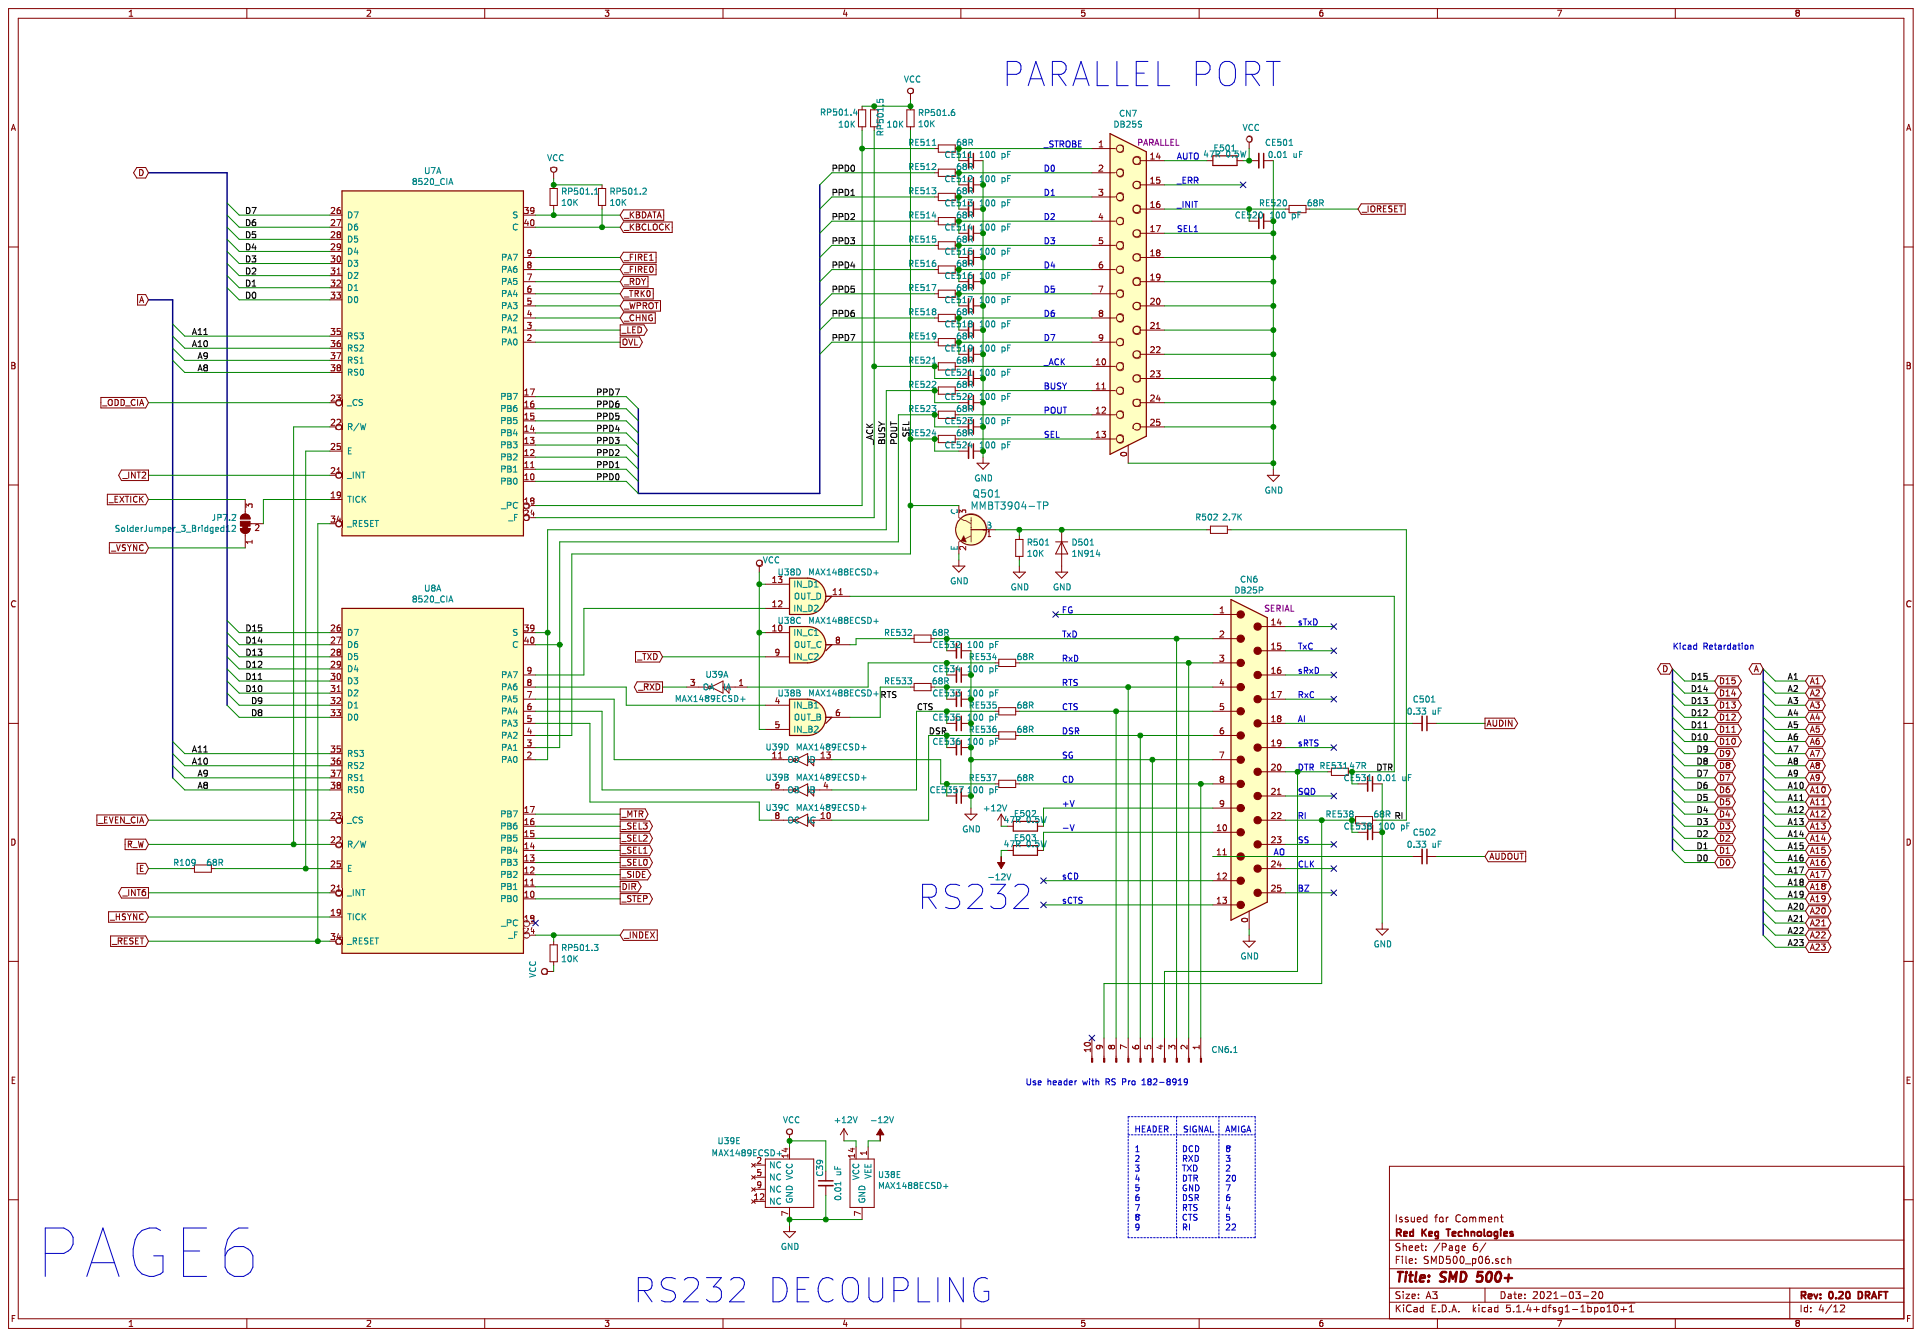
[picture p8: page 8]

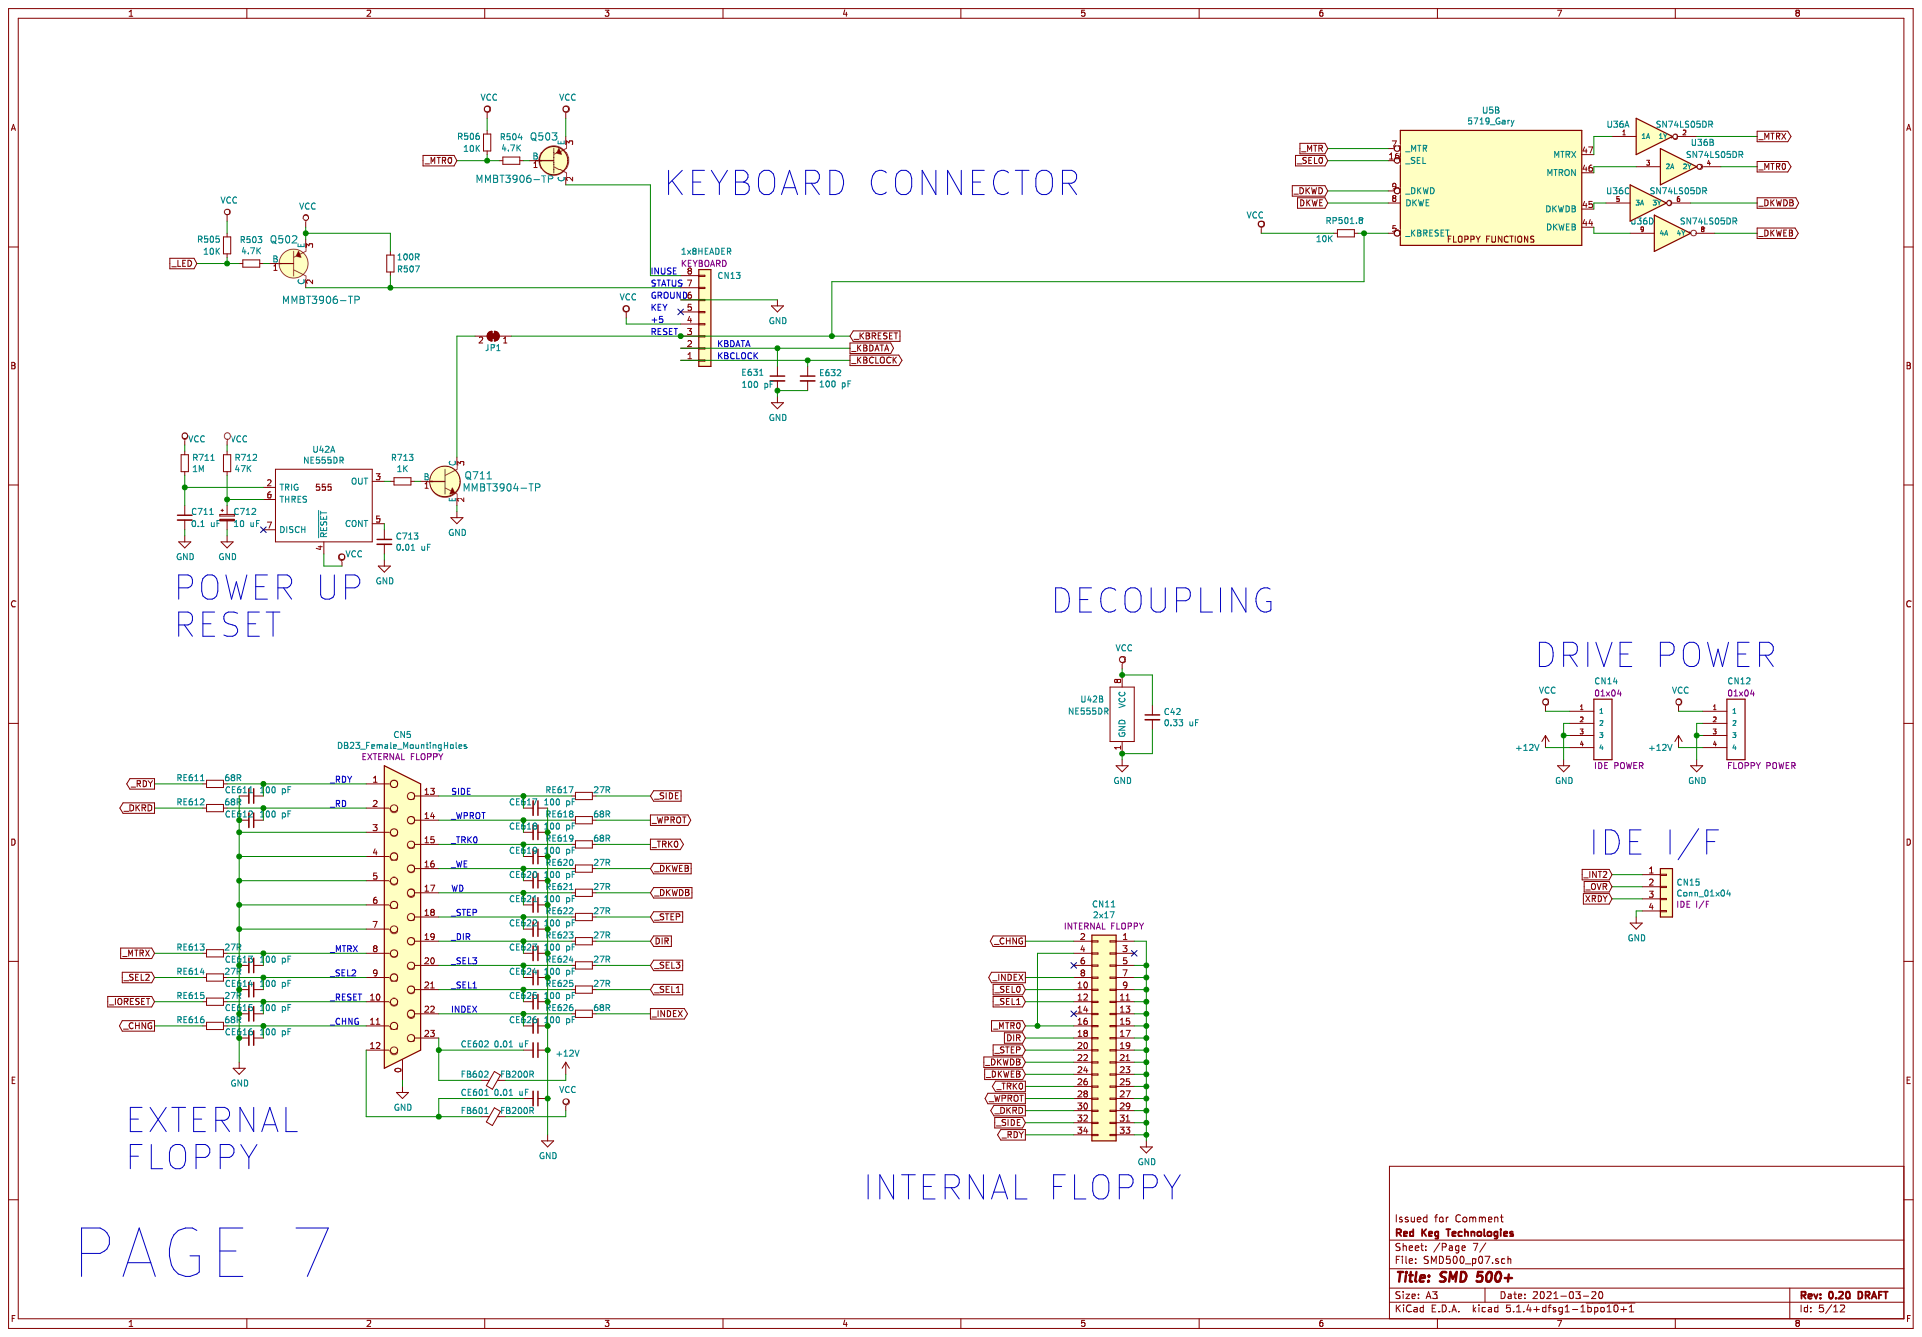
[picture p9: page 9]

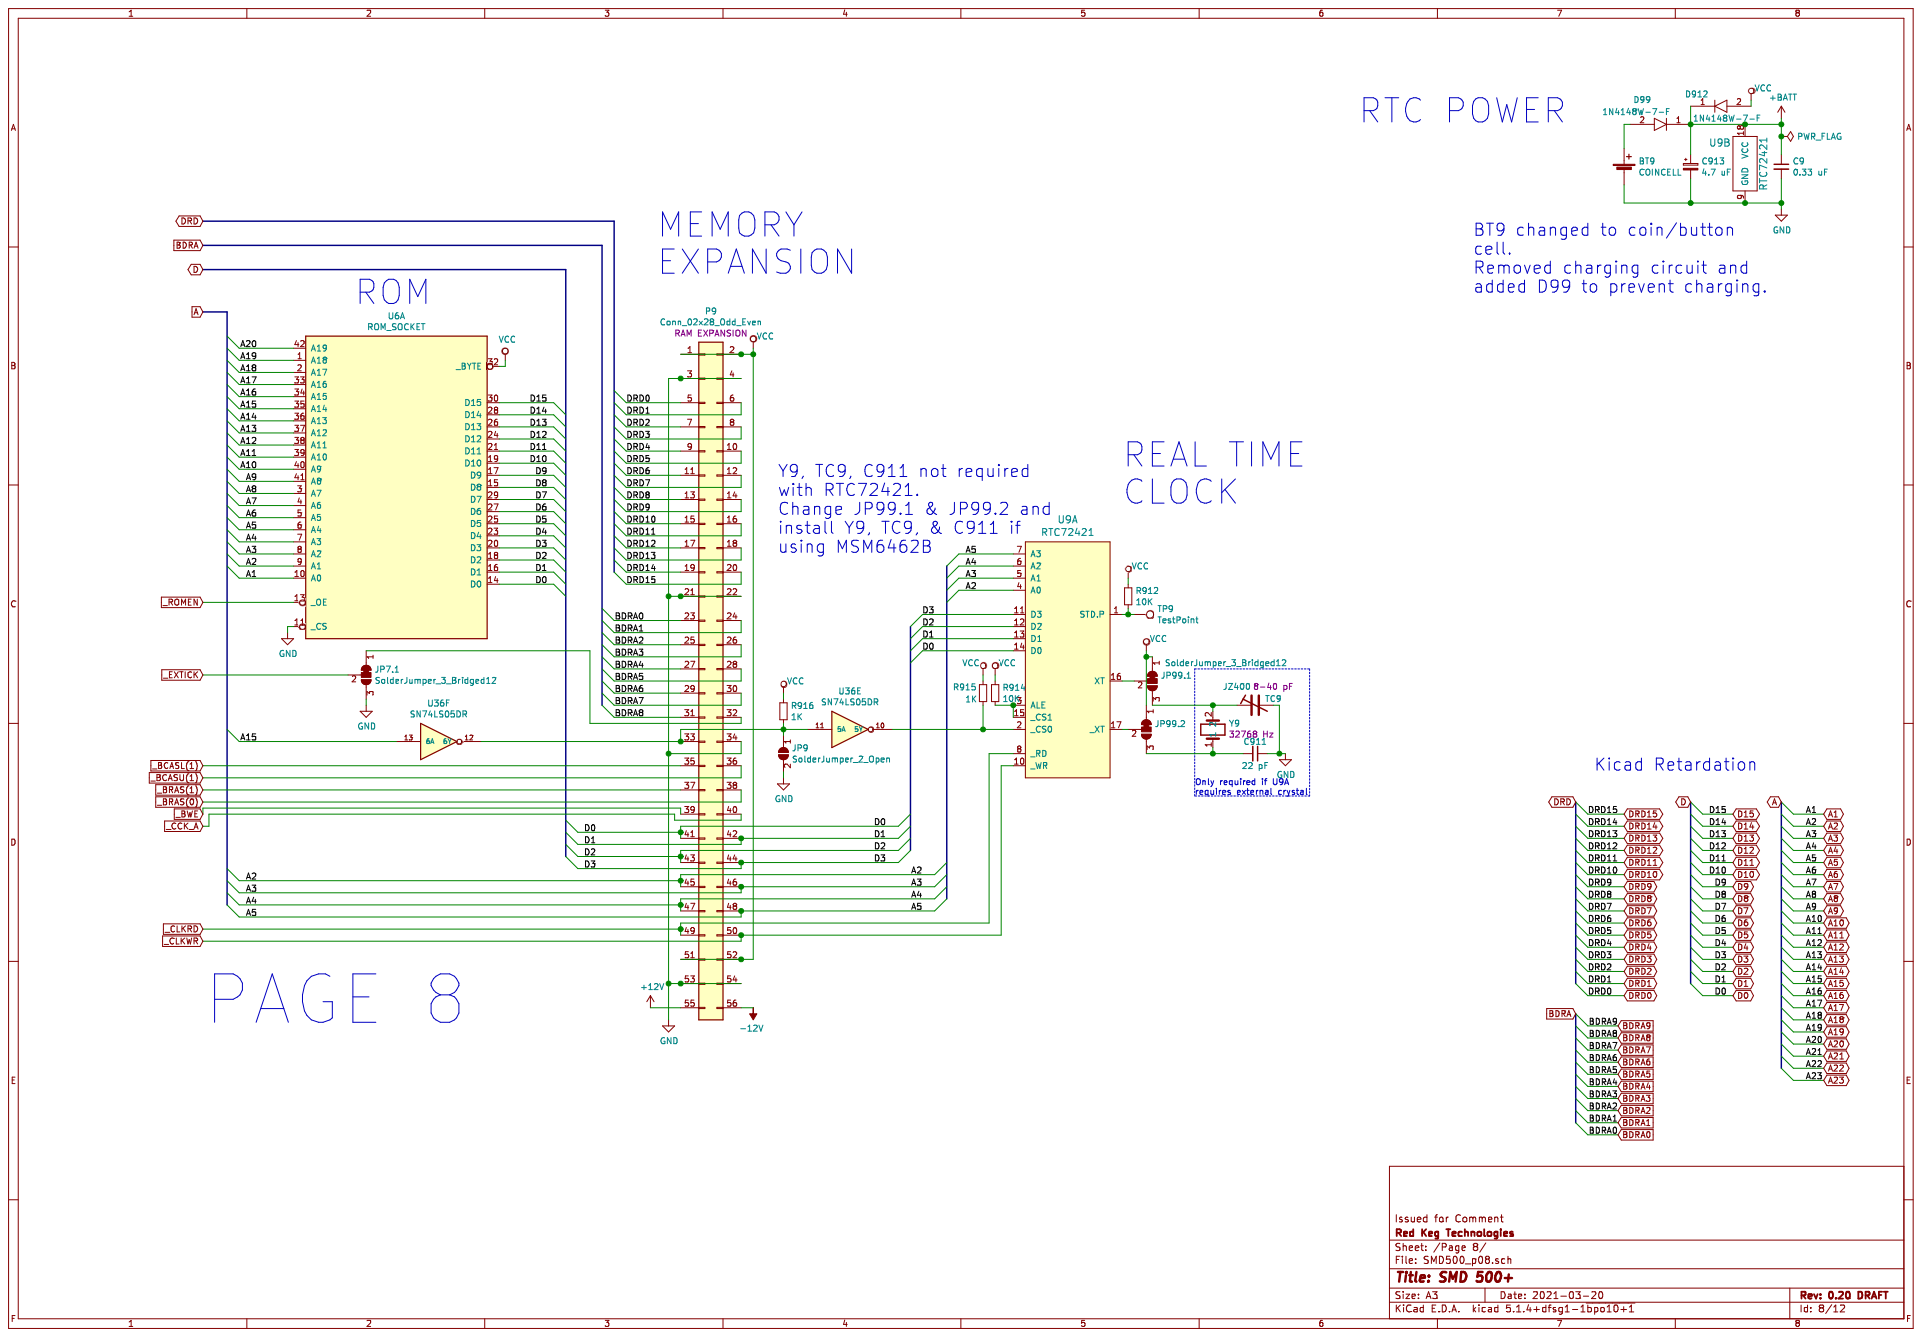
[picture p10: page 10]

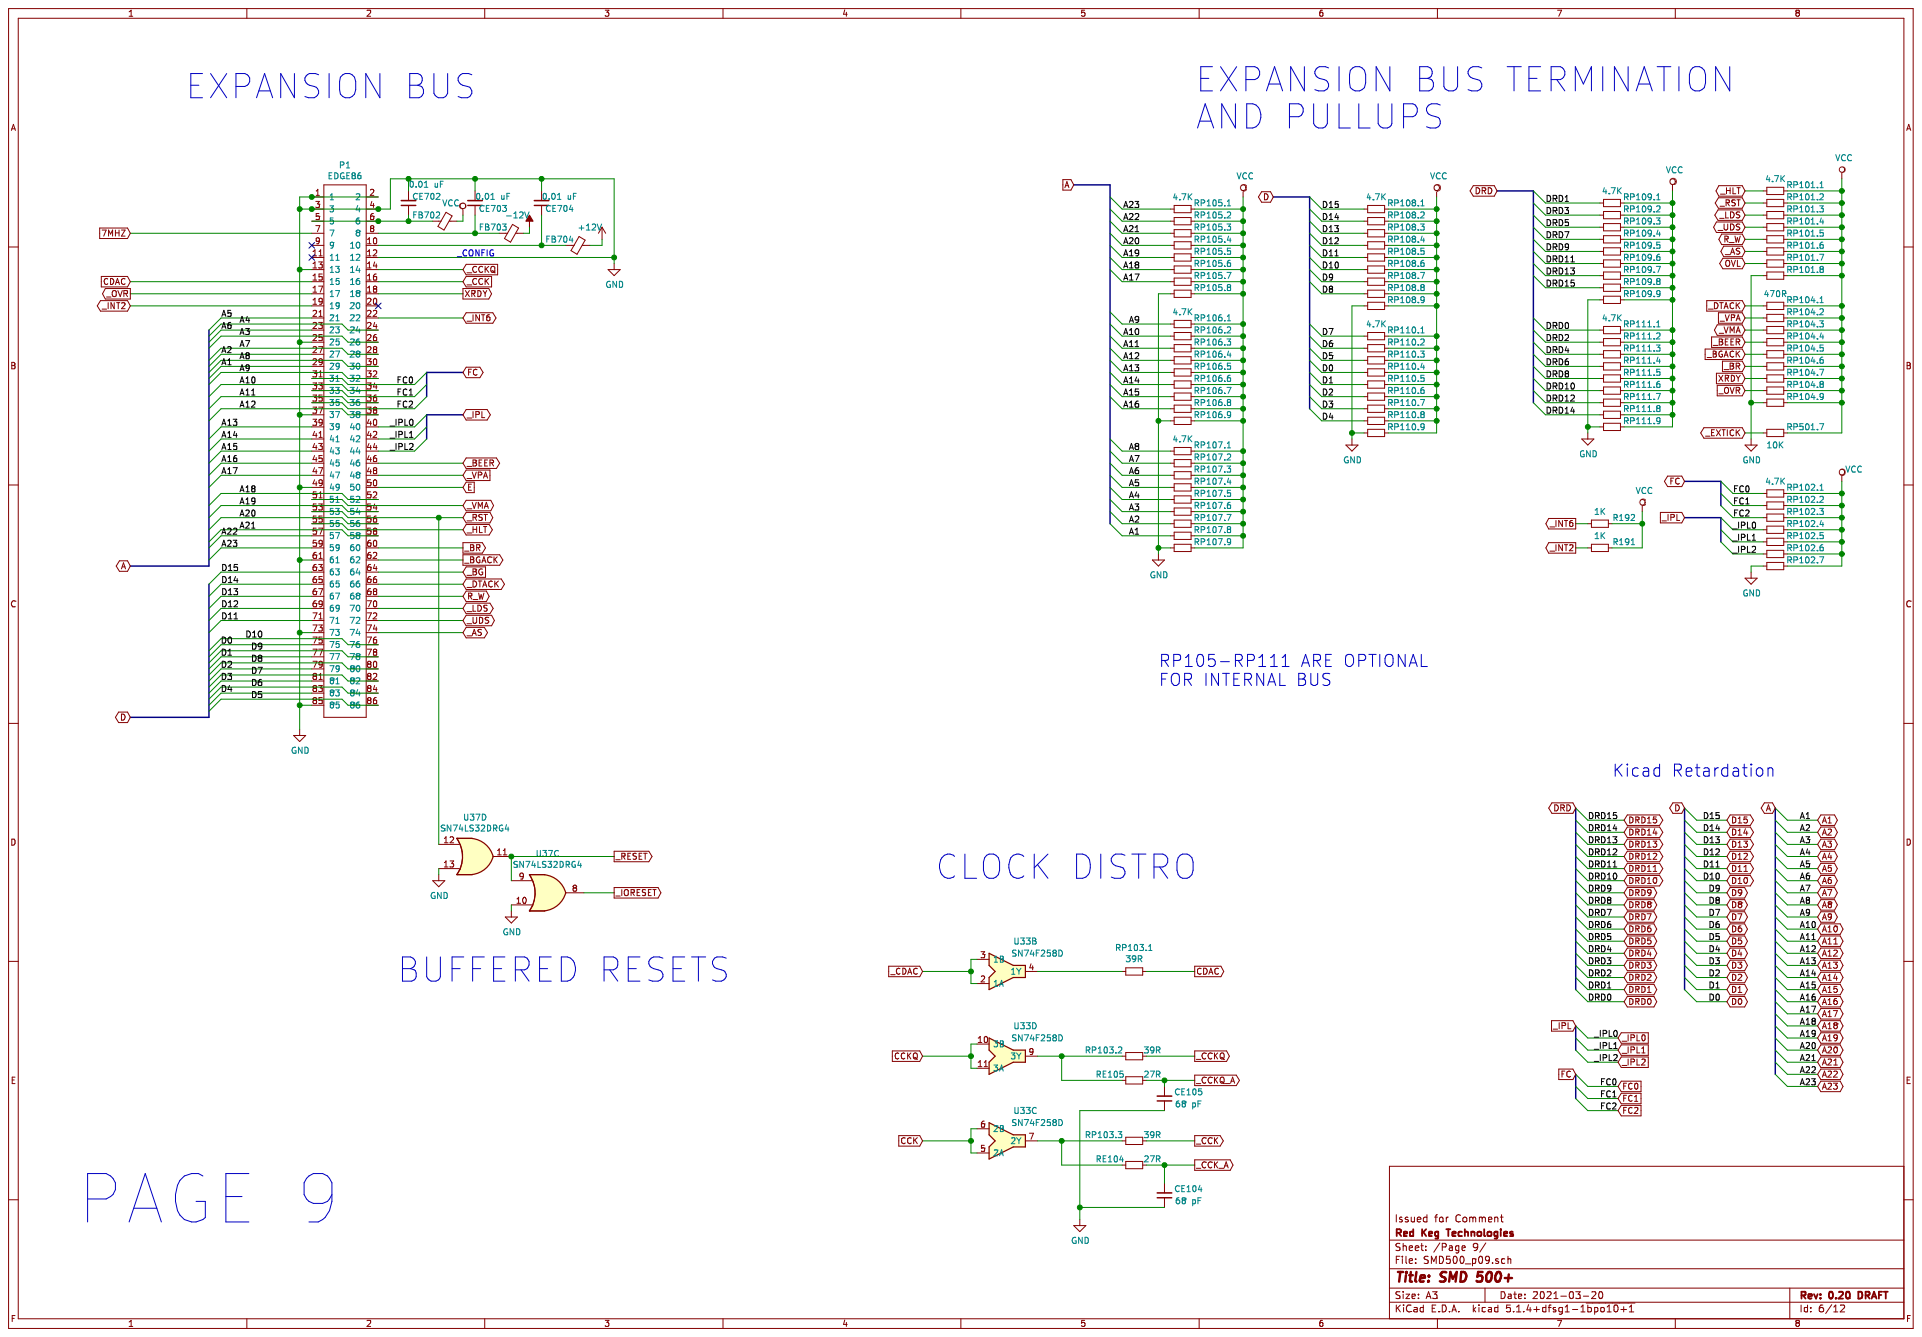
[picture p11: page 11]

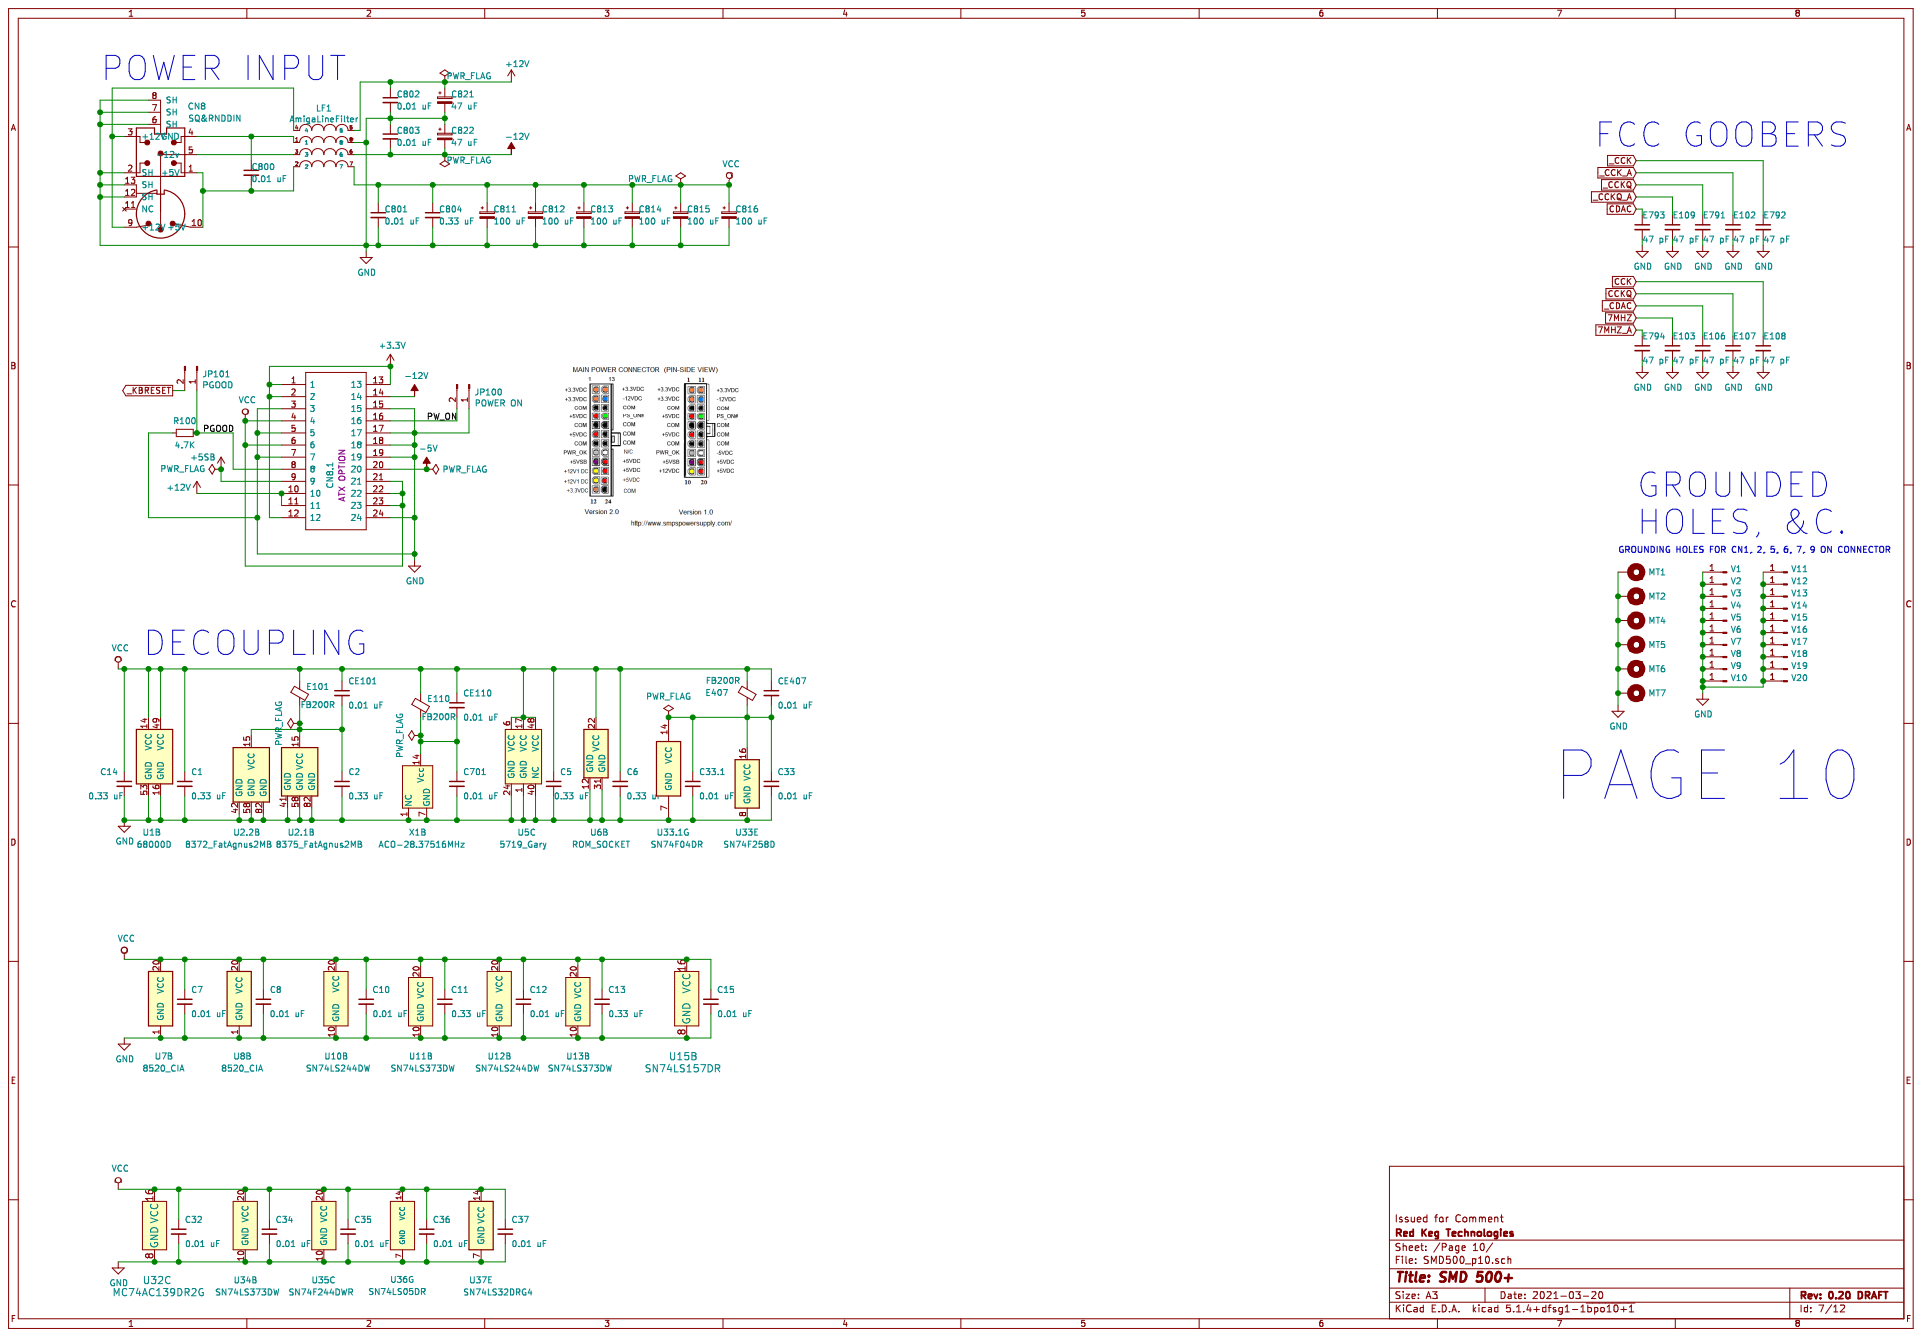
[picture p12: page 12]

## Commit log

2019-10-08 Add files via upload
    Fix for missing silkscreen on some pads
2019-11-12 Add files via upload
    Minor revision to fix problem with solder mask
    [SMD500.sch]
2019-11-12 Add files via upload
    Minor revision to fix solder mask issue
    [SMD500-B_Cu.gbr, SMD500-B_Mask.gbr, SMD500-B_Paste.gbr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]
2021-03-20 Add files via upload
    New schematics file for comment
